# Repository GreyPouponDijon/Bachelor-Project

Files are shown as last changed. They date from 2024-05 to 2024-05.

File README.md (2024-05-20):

# Bachelor-Project
This project focused on developing a motion-controlled game for the Game Boy Pocket, integrating modern sensor technology with classic gaming hardware. The game, a first-person flying simulator, uses an accelerometer to detect motion, allowing players to control an aircraft by tilting the device. The accelerometer data is transmitted via SPI through a custom-made link cable, ensuring real-time movement.

Key Components
Game Development: Designed and programmed using GBDK-2020.
Sensor Integration: Implemented accelerometer data transmission via SPI.
Bluetooth Connectivity: Established connections using an nRF5340 module for multiplayer functionality, enabling competitive and cooperative gameplay.
Hardware Design: Created a prototype PCB to facilitate the integration process.
Challenges and Solutions
Hardware and Software Integration: Optimized performance within the constraints of the Game Boy Pocket’s limited memory and processing power.
Development Documentation: Thoroughly documented the development process from initial design to final implementation, detailing the methods used to overcome various challenges.
This project showcases the blend of retro gaming with modern technology, providing an innovative gaming experience on classic hardware.

The project report, PCB schematic, PCB files production files, BOM and code is available in this repo

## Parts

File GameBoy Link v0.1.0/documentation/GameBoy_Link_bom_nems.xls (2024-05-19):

Bill of material
Board: | <Parameter PCAName not found>
Version: | <Parameter PCARevision not found>
Number of boards: | 1
Designator | PartId | Total needed | Comment | Value | Footprint Doc | Description | Assembly | Layer | Quantity | Part number NEMS | Manufacturer | Manufacturer Part Number | Supplier 1 | Supplier Part Number 1 | Supplier 2 | Supplier Part Number 2
C1 | 100200441 | 1 |  | 0.7pF | 0201 | Capacitor, Ceramic, NP0, ±0.1pF, 25V |  | Top | 1 | 100200441 | Murata | GJM0335C1ER70BB01D | Digi-Key | 490-8076-1-ND | N.A. | N.A.
C2, C3, C5, C7, C16, C22 | 100200497 | 6 |  | 1.0µF | 0402 | Capacitor, Ceramic, 1.0µF 10V X7S 0402,±10% |  | Top | 6 | 100200497 | Murata | GRM155C71A105KE11 | Mouser | 81-GRM155C71A105KE1J | Digi-Key | 490-14457-1-ND
C4 | 100200060 | 1 |  | 2.2nF | 0201 | Capacitor, X7R, ±10%, 10V |  | Top | 1 | 100200060 | N.A. | N.A. | N.A. | N.A. | N.A. | N.A.
C6, C8, C9, C10, C11, C12, C13, C14, C15 | 100200403 | 9 |  | 100nF | 0201 | Capacitor, X7S, 16V |  | Top | 9 | 100200403 | Murata | GRM033C71C104KE14D | Digi-Key | 490-10387-1-ND | N.A. | N.A.
C17, C20 | 100200351 | 2 |  | 4.7µF | 0603 | Capacitor, X7S, ±10%, 10V |  | Top | 2 | 100200351 | N.A. | N.A. | Digi-Key | 445-14258-1-ND | N.A. | N.A.
C18 | 100200350 | 1 |  | 4.7µF | 0603 | Capacitor, X7R, ±10%, 6.3V |  | Top | 1 | 100200350 | Samsung Electro-Mechanics America | CL10B475KQ8NQNC | Digi-Key | 1276-2087-1-ND | N.A. | N.A.
C19 | 100200272 | 1 |  | 2.2µF | 0603 | Capacitor, X7R, ±10% |  | Top | 1 | 100200272 | N.A. | N.A. | N.A. | N.A. | N.A. | N.A.
C21 |  | 1 |  | N.C. | 0201 | Not mounted | Not mounted | Top | 1
C23 | 100200119 | 1 |  | 1.2pF | 0402 | Capacitor, NP0, ±0.1pF |  | Top | 1 | 100200119 | N.A. | N.A. | N.A. | N.A. | N.A. | N.A.
J1 | 100500400 | 1 |  | MM8130-2600 | COAXIAL-SWF | Coaxial Connector with Switch |  | Top | 1 | 100500400 | Murata | MM8130-2600 | Digi-Key | 490-4981-1-ND | Mouser | 81-MM8130-2600RA2
L1 | 100300209 | 1 |  | 2.2nH | 0201 | Inductor, 600mA, ±0.1ｎH, 120mOhm |  | Top | 1 | 100300209 | Murata | LQP03HQ2N2B02 | Digi-Key | 490-13899-1-ND | N.A. | N.A.
L2, L3, L4 | 100300078 | 3 |  | 10µH | 0603 | Inductor, 80mA, ±10% |  | Top | 3 | 100300078 | Taiyo Yuden | LBMF1608T100K | Digi-Key | 587-1714-1-ND | Farnell | 178-6105
LD1 | 101400017 | 1 |  | L0805G | 0805 | LED, SMD, 0805, GREEN |  | Top | 1 | 101400017 | Rohm Semiconductor | SML-210PTT86 | N.A. | N.A. | N.A. | N.A.
P1 | 100500318 | 1 |  | Pin List 1x6 | LIST_1x6 | Pin List 1x6, 2.54mm (100mil) |  | Top | 1 | 100500318 | N.A. | N.A. | N.A. | N.A. | N.A. | N.A.
P2 | 100500298 | 1 |  | Pin List 1x2 | LIST_1x2 | Pin List 1x2, 2.54mm (100mil) | Not mounted | Top | 1 | 100500298 | N.A. | N.A. | N.A. | N.A. | N.A. | N.A.
P3 | 100500261 | 1 |  | Pin Header 2x5, 1.27mm | HDR_2x5-SMD-1.27mm | Pin Header 2x5, 1.27mm (50mil), SMD, Keying Shroud |  | Top | 1 | 100500261 | WCON | 3132-10MS0BK00R5 | Cabcon | 3132-10MS0BK00R5 | N.A. | N.A.
R1 | 100100006 | 1 |  | 2R2 | 0201 | Resistor, ±1%, 0.05W |  | Top | 1 | 100100006 | N.A. | N.A. | N.A. | N.A. | N.A. | N.A.
R2 | 100100171 | 1 |  | 1k | 0402 | Resistor, ±1%, 0.063W |  | Top | 1 | 100100171 | N.A. | N.A. | Farnell | 173-8850 | N.A. | N.A.
SW1 | 101500001 | 1 |  | PB SW | Switch-PB-6.2x6.3mm-SMD | Tactile Switch, SPNO, SMD, 160gf, 6.2x6.3x2.5mm | DNM | Top | 1 | 101500001, 101500133 | Dailywell | TS604VM1-025BR-R | Cabcon | TS604VM1-025BR-R | Mouser | 688-SKHUALE010
U1 | 102000153 | 1 |  | nRF5340-QKAA | AQFN-98 | Multi-protocol Bluetooth Low Energy, IEEE 802.15.4, ANT and 2.4GHz proprietary system-on-chip |  | Top | 1 | 102000153 | Nordic Semiconductor | nRF5340-QKAA | Nordic Semiconductor | nRF5340-QKAA | N.A. | N.A.
U2 | 101900620 | 1 |  | BMI270 | LGA-14 | 6-axis, smart, low-power, inertial measurement unit |  | Top | 1 | 101900620 | Bosch | BMI270 | Digi-Key | 828-1091-1-ND | Mouser | 262-BMI270
X1 | 101600041 | 1 |  | 32MHz | XTAL_2016 | XTAL SMD 2016, 32MHz, Cl=8pF, Tol: ±10ppm, Stab: ±15ppm |  | Top | 1 | 101600041 | Golledge | MP06003 | Link Nordic | N.A. | N.A. | N.A.
PCB |  | 1 |  | <Parameter PCBNumber not found> | <Parameter PCBRevision not found> |  |  |  | 1
All components must be RoHS compliant

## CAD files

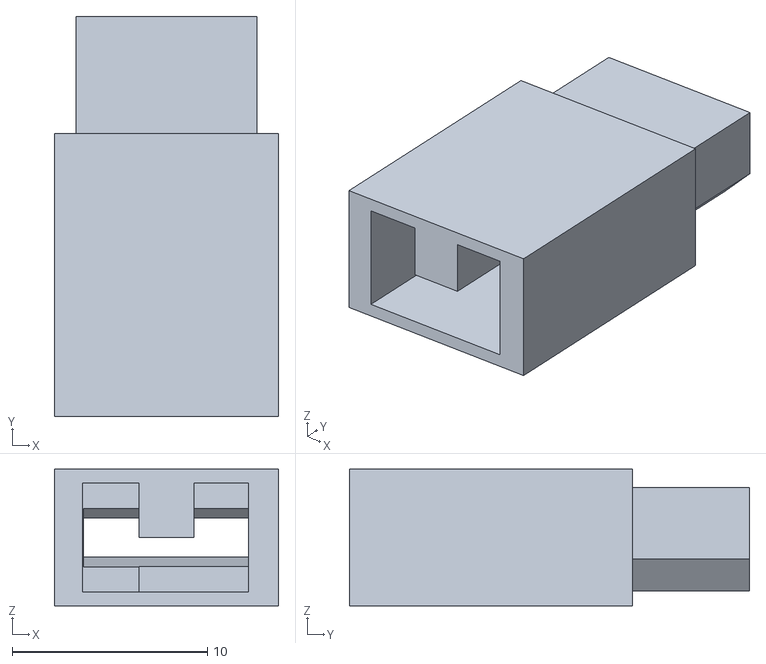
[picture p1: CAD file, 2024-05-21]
Link Cable GBP.stl
11.5 x 20.5 x 7.00

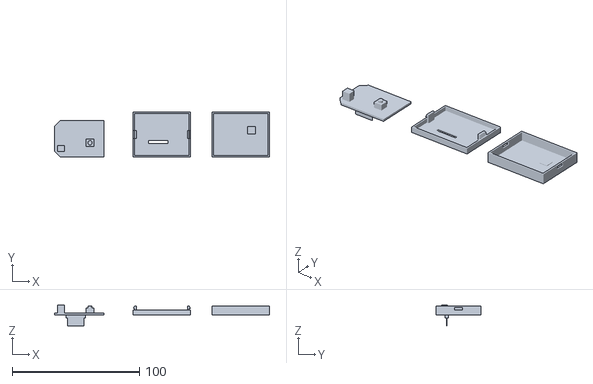
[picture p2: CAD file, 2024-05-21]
Gamelink.stl
168.7 x 35.0 x 16.1

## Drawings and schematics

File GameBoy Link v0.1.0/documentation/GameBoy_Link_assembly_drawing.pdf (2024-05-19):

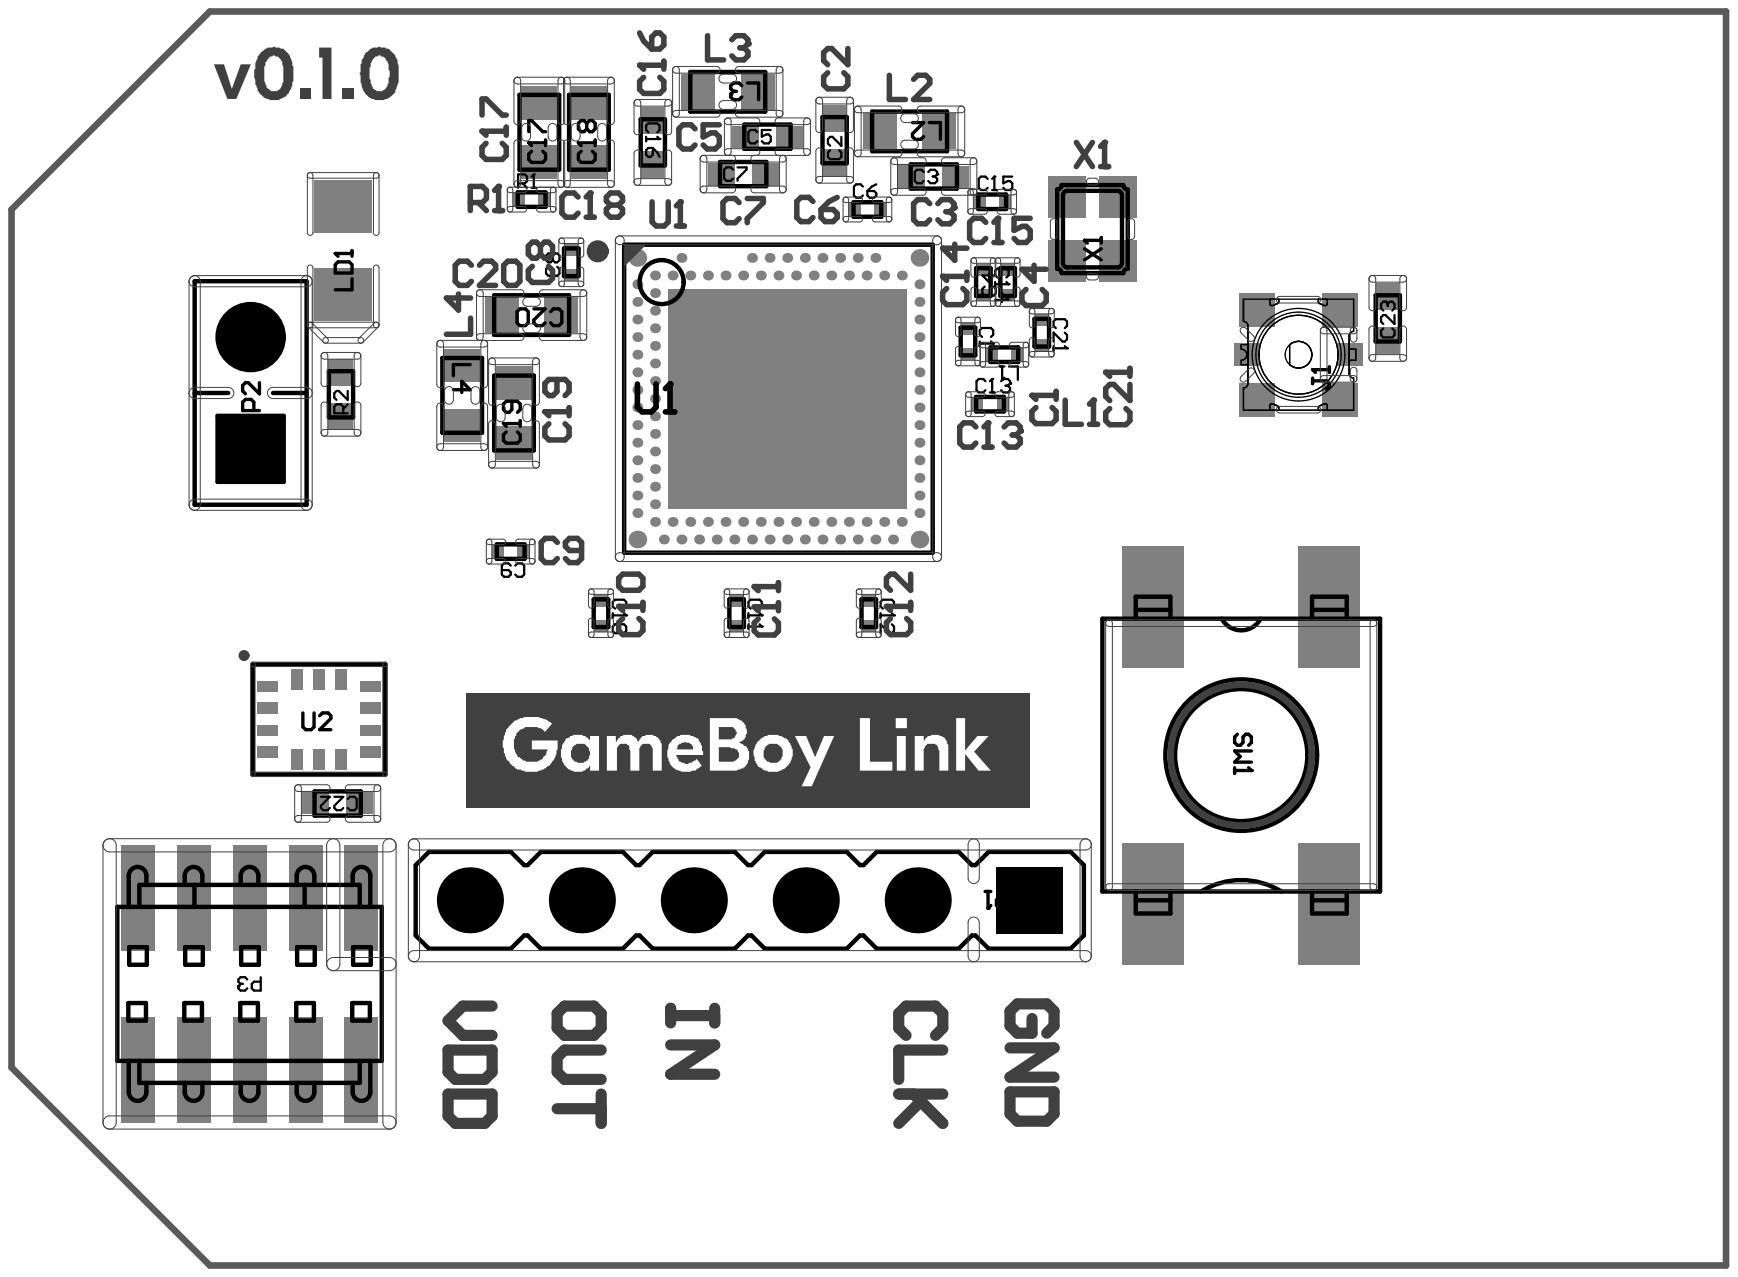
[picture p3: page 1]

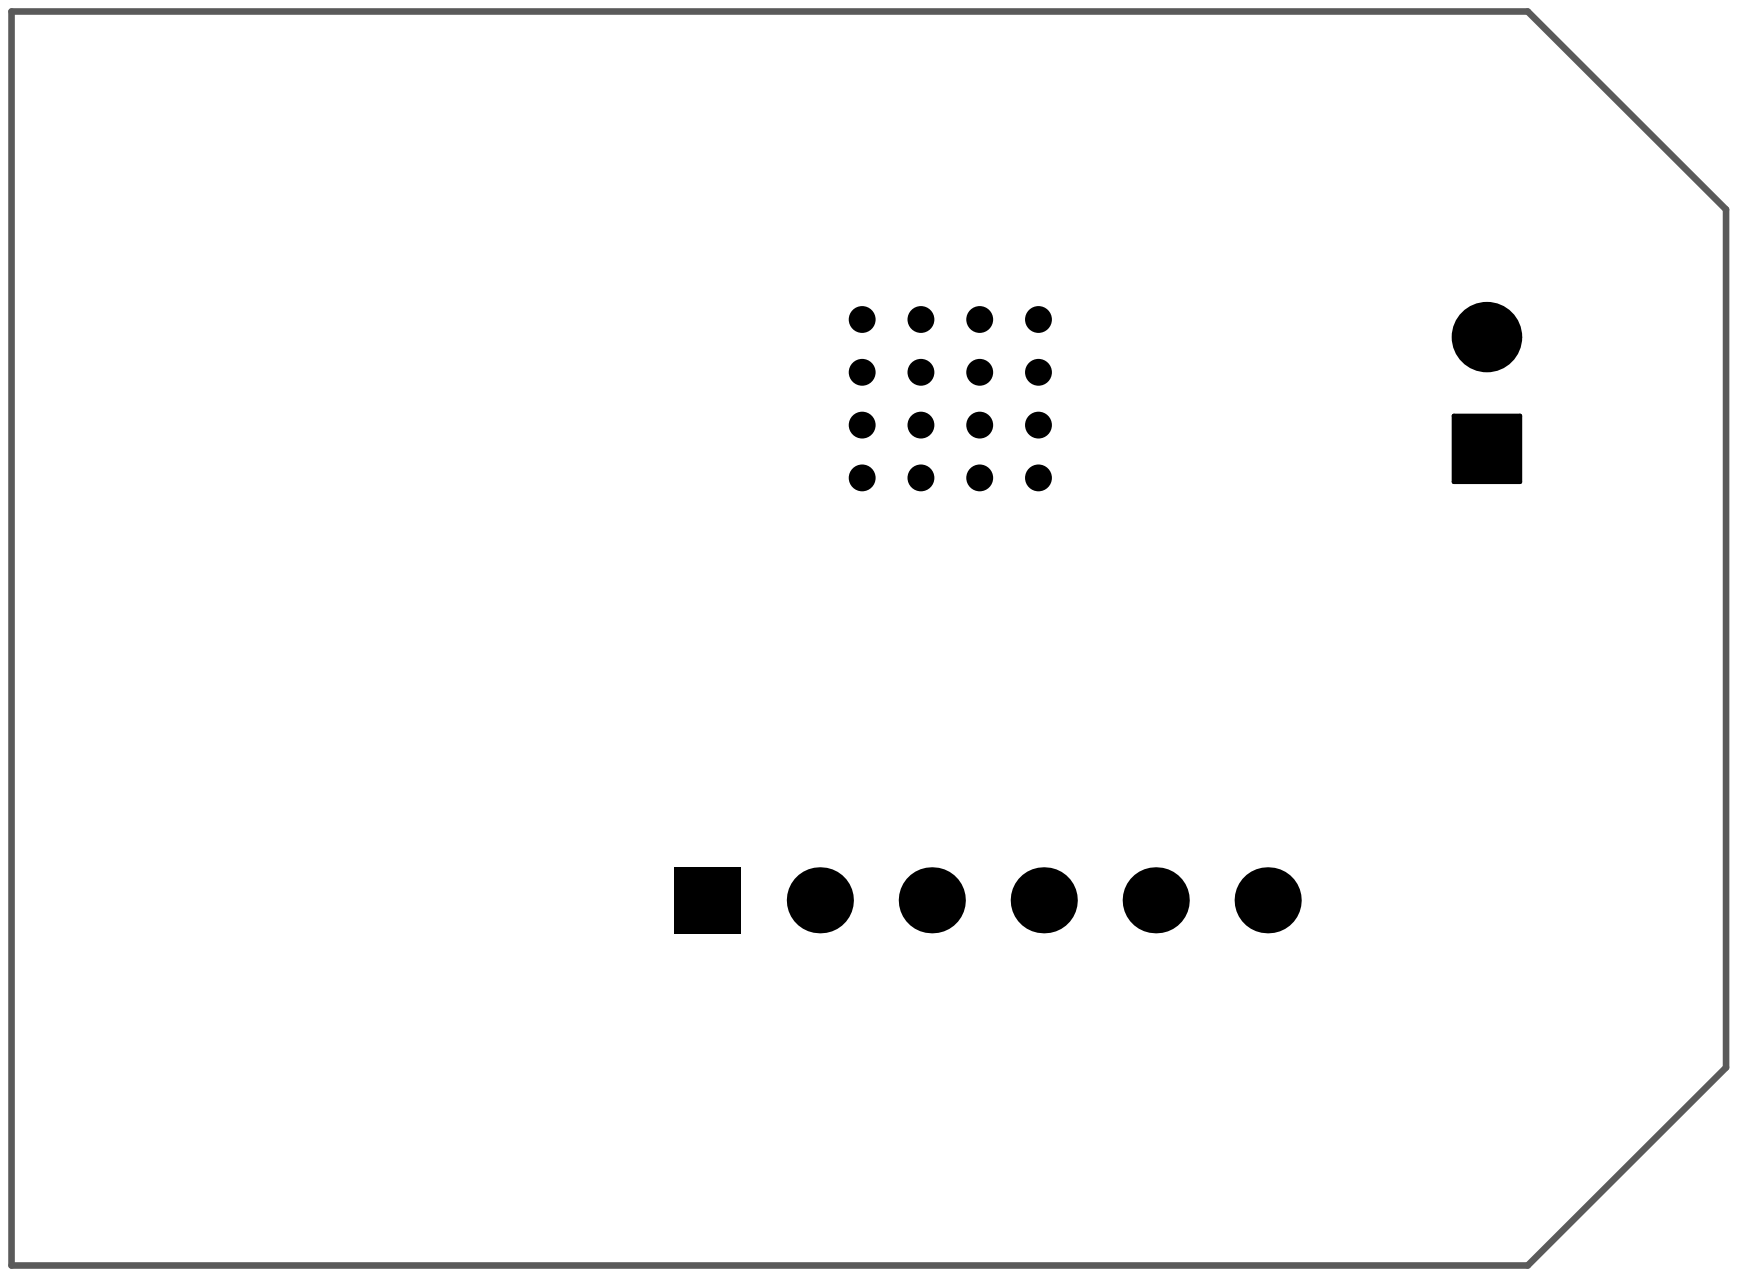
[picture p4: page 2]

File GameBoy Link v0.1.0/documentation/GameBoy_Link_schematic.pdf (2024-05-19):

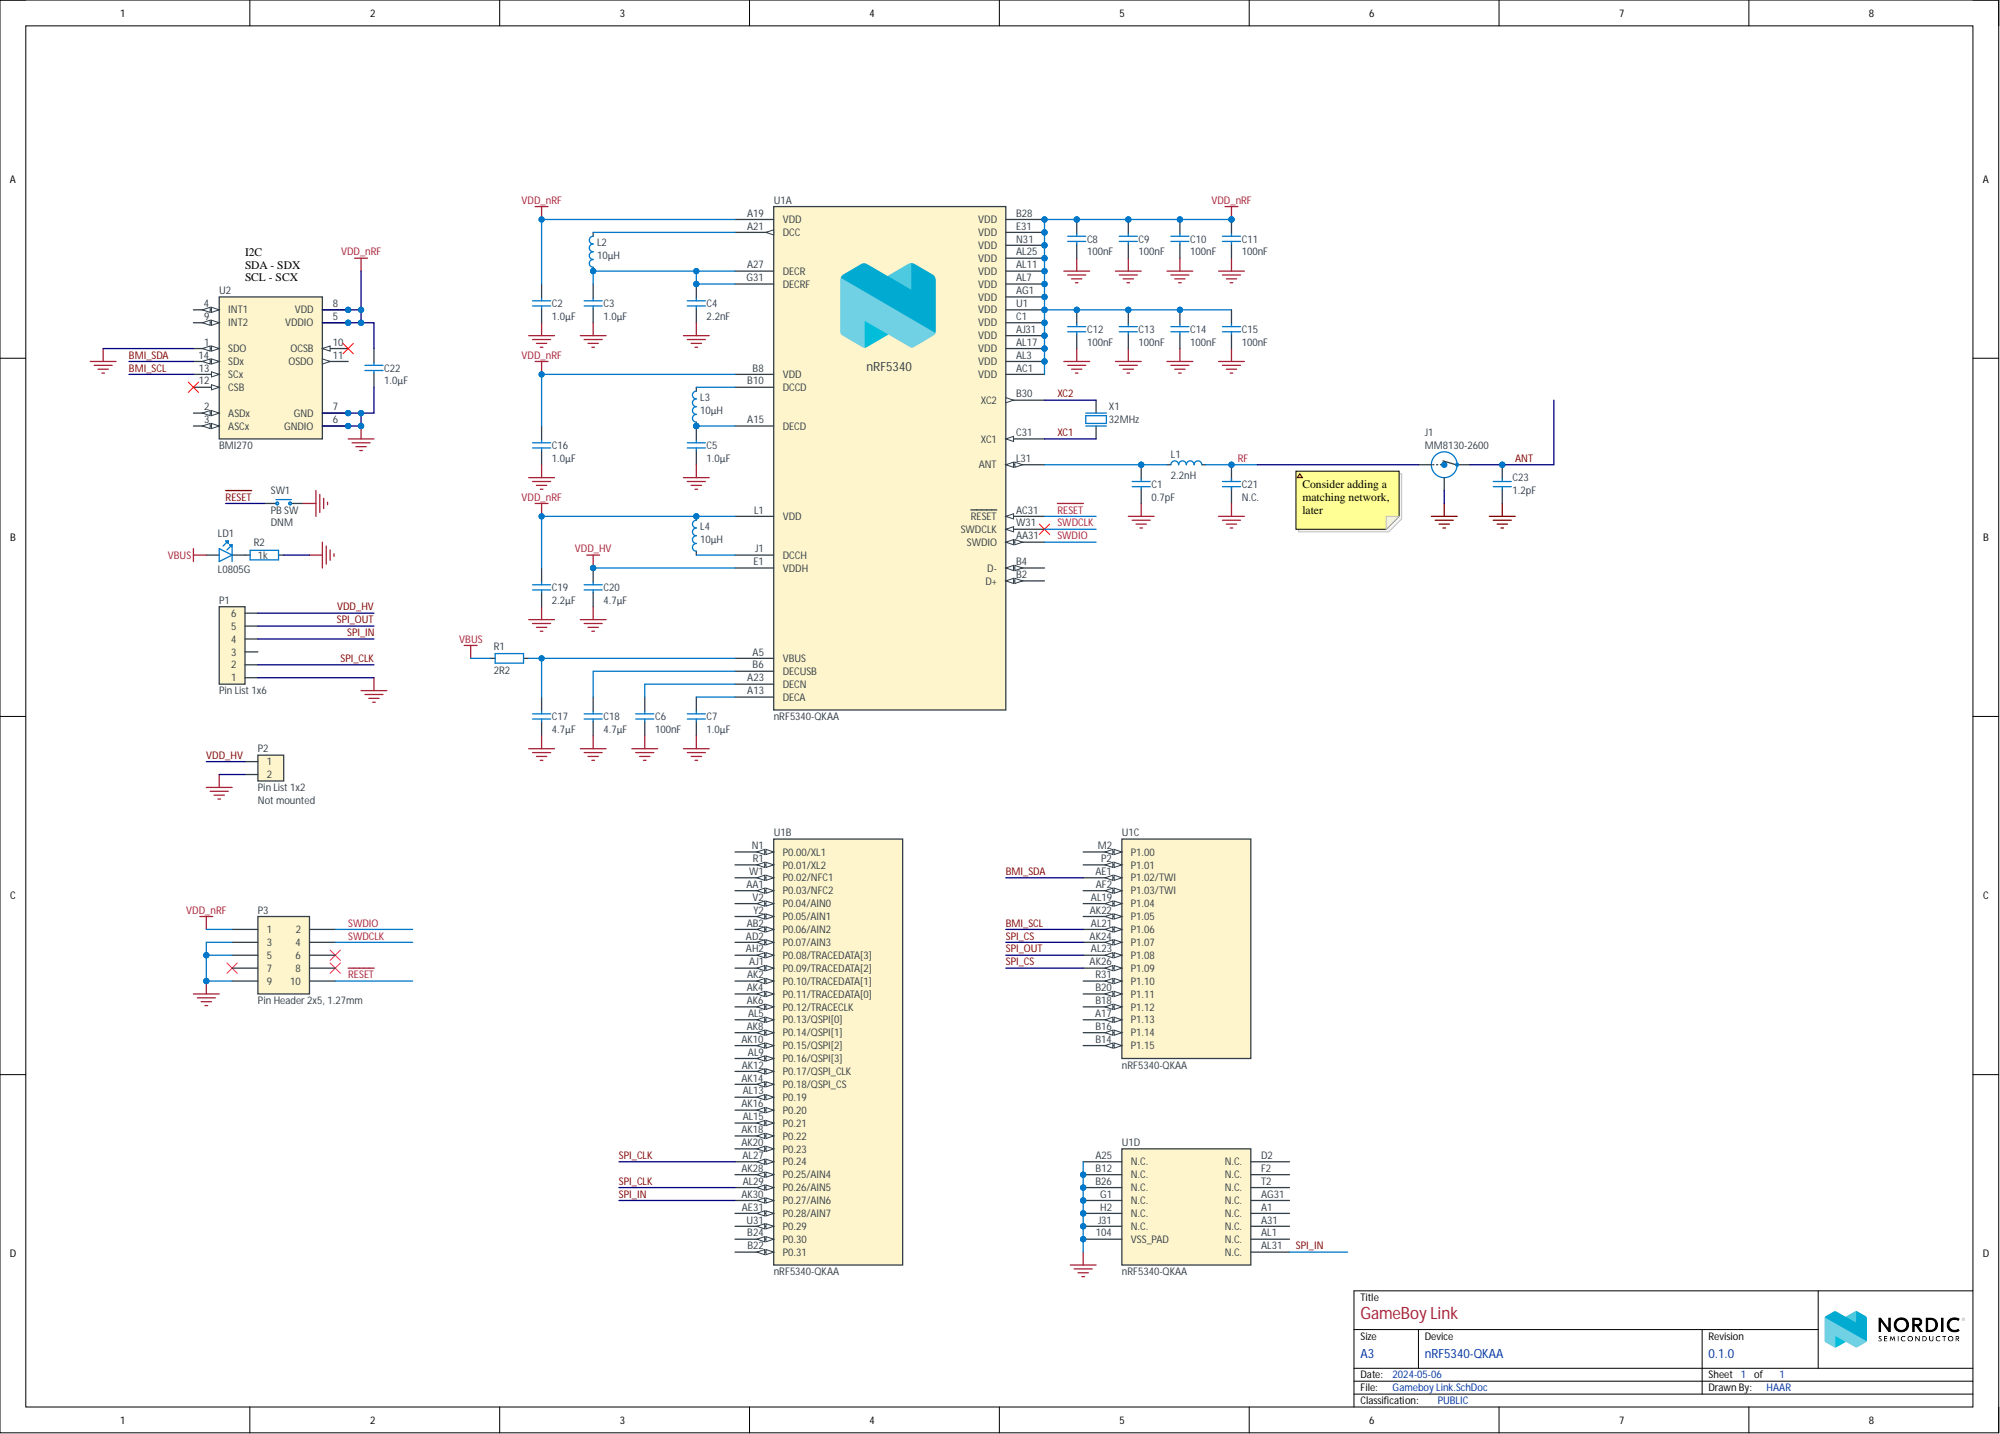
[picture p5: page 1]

DCC A21

DECRF G31

VDD B8
DCCD B10

VBUS A5

DECA A13 DECN A23

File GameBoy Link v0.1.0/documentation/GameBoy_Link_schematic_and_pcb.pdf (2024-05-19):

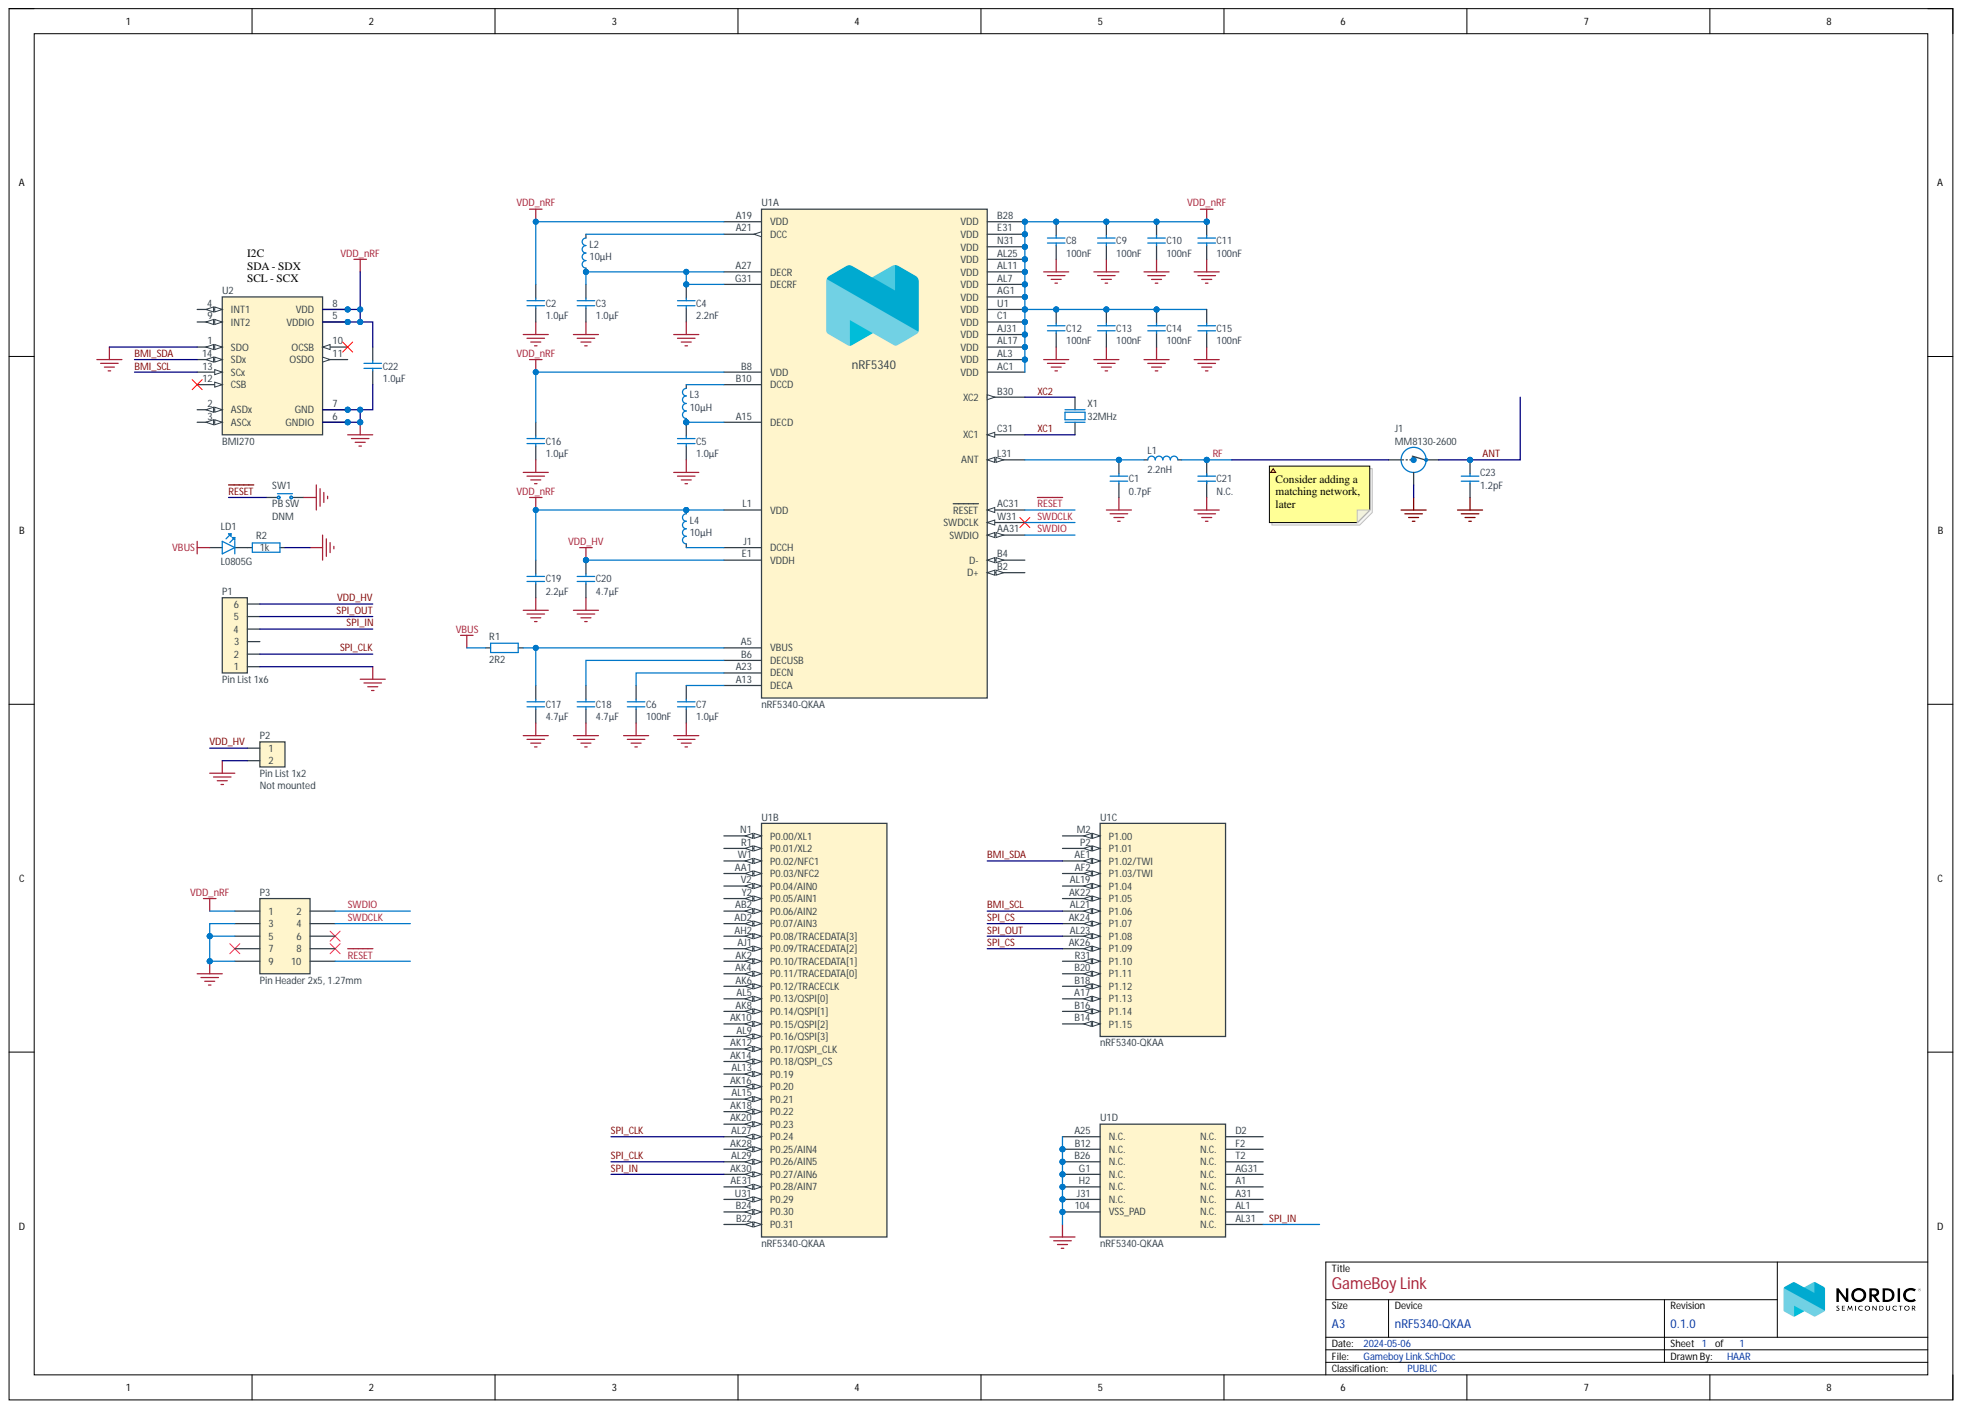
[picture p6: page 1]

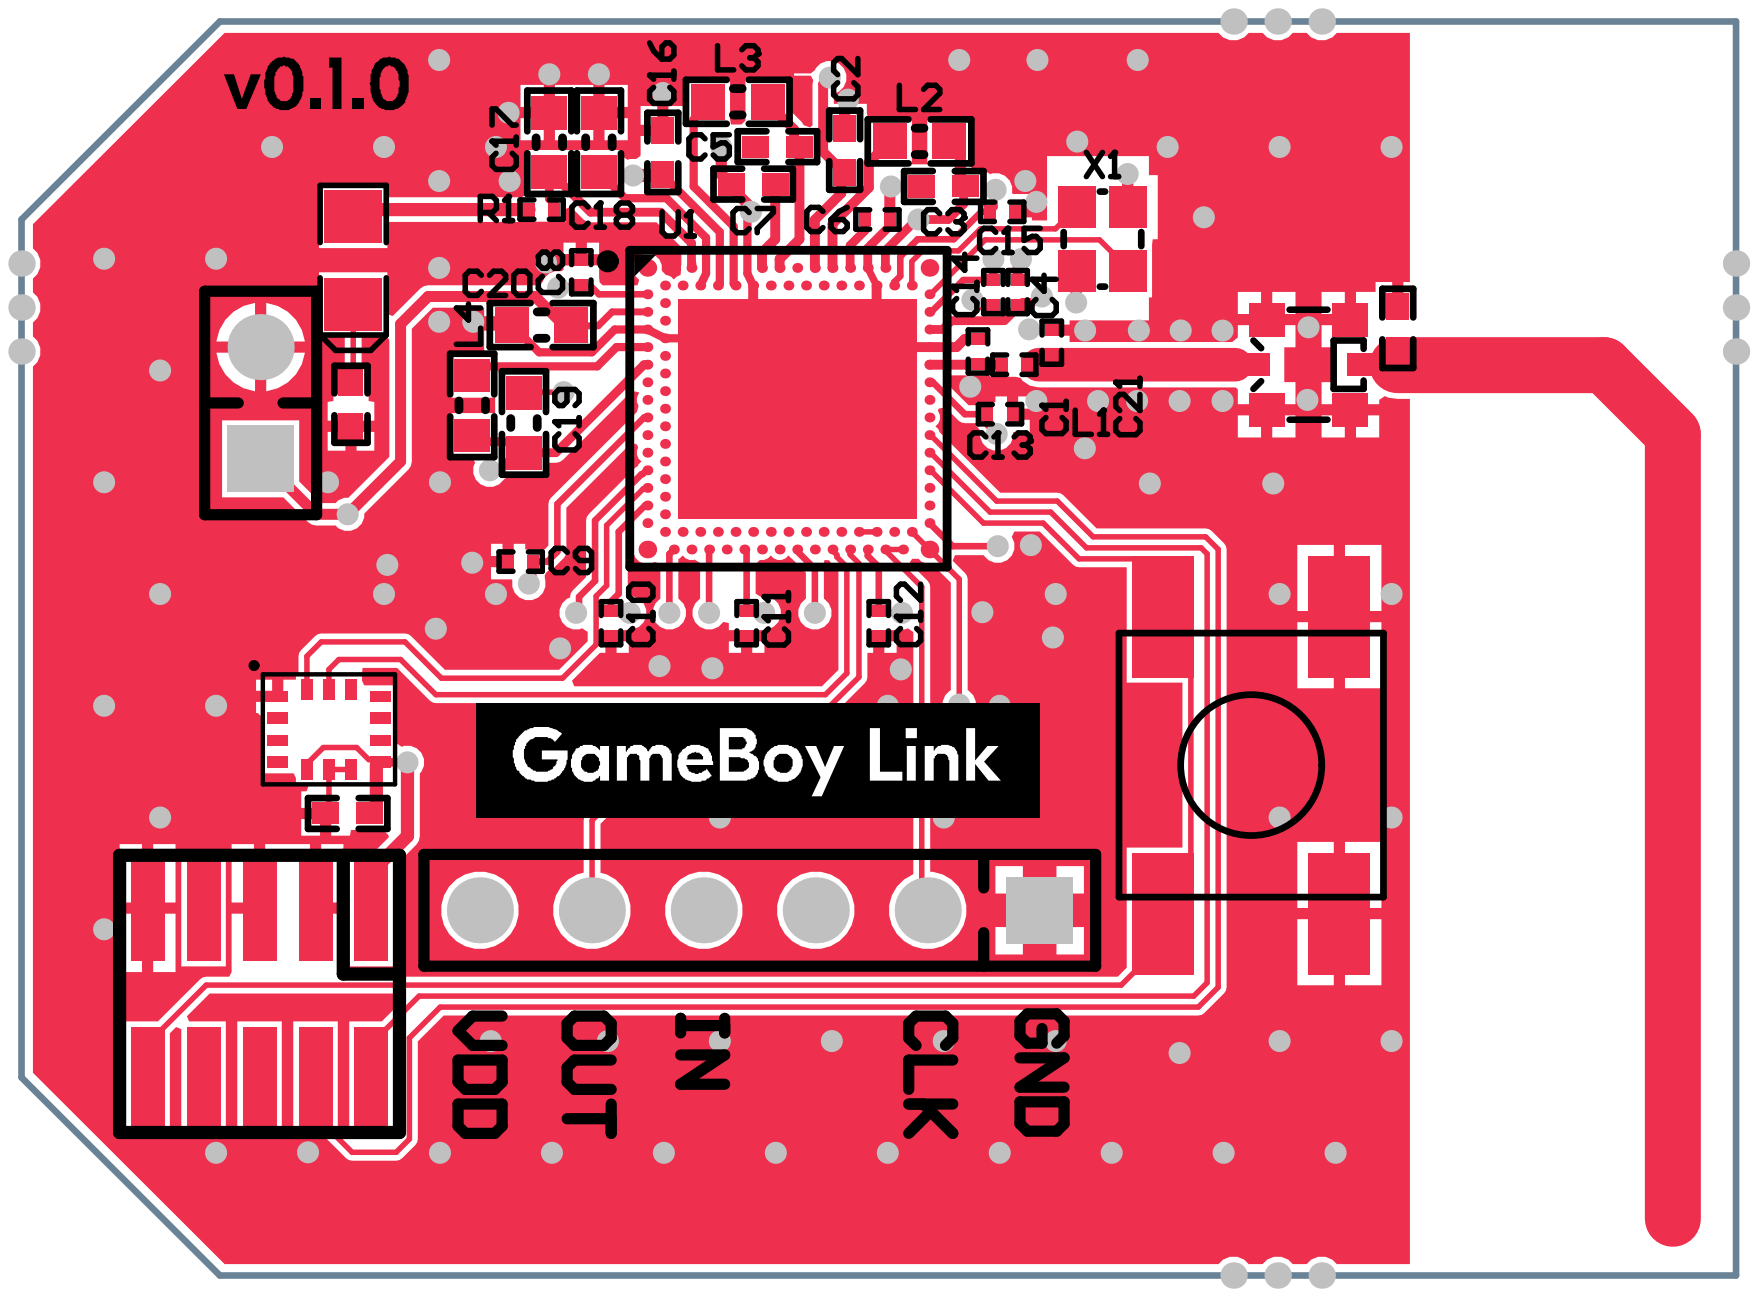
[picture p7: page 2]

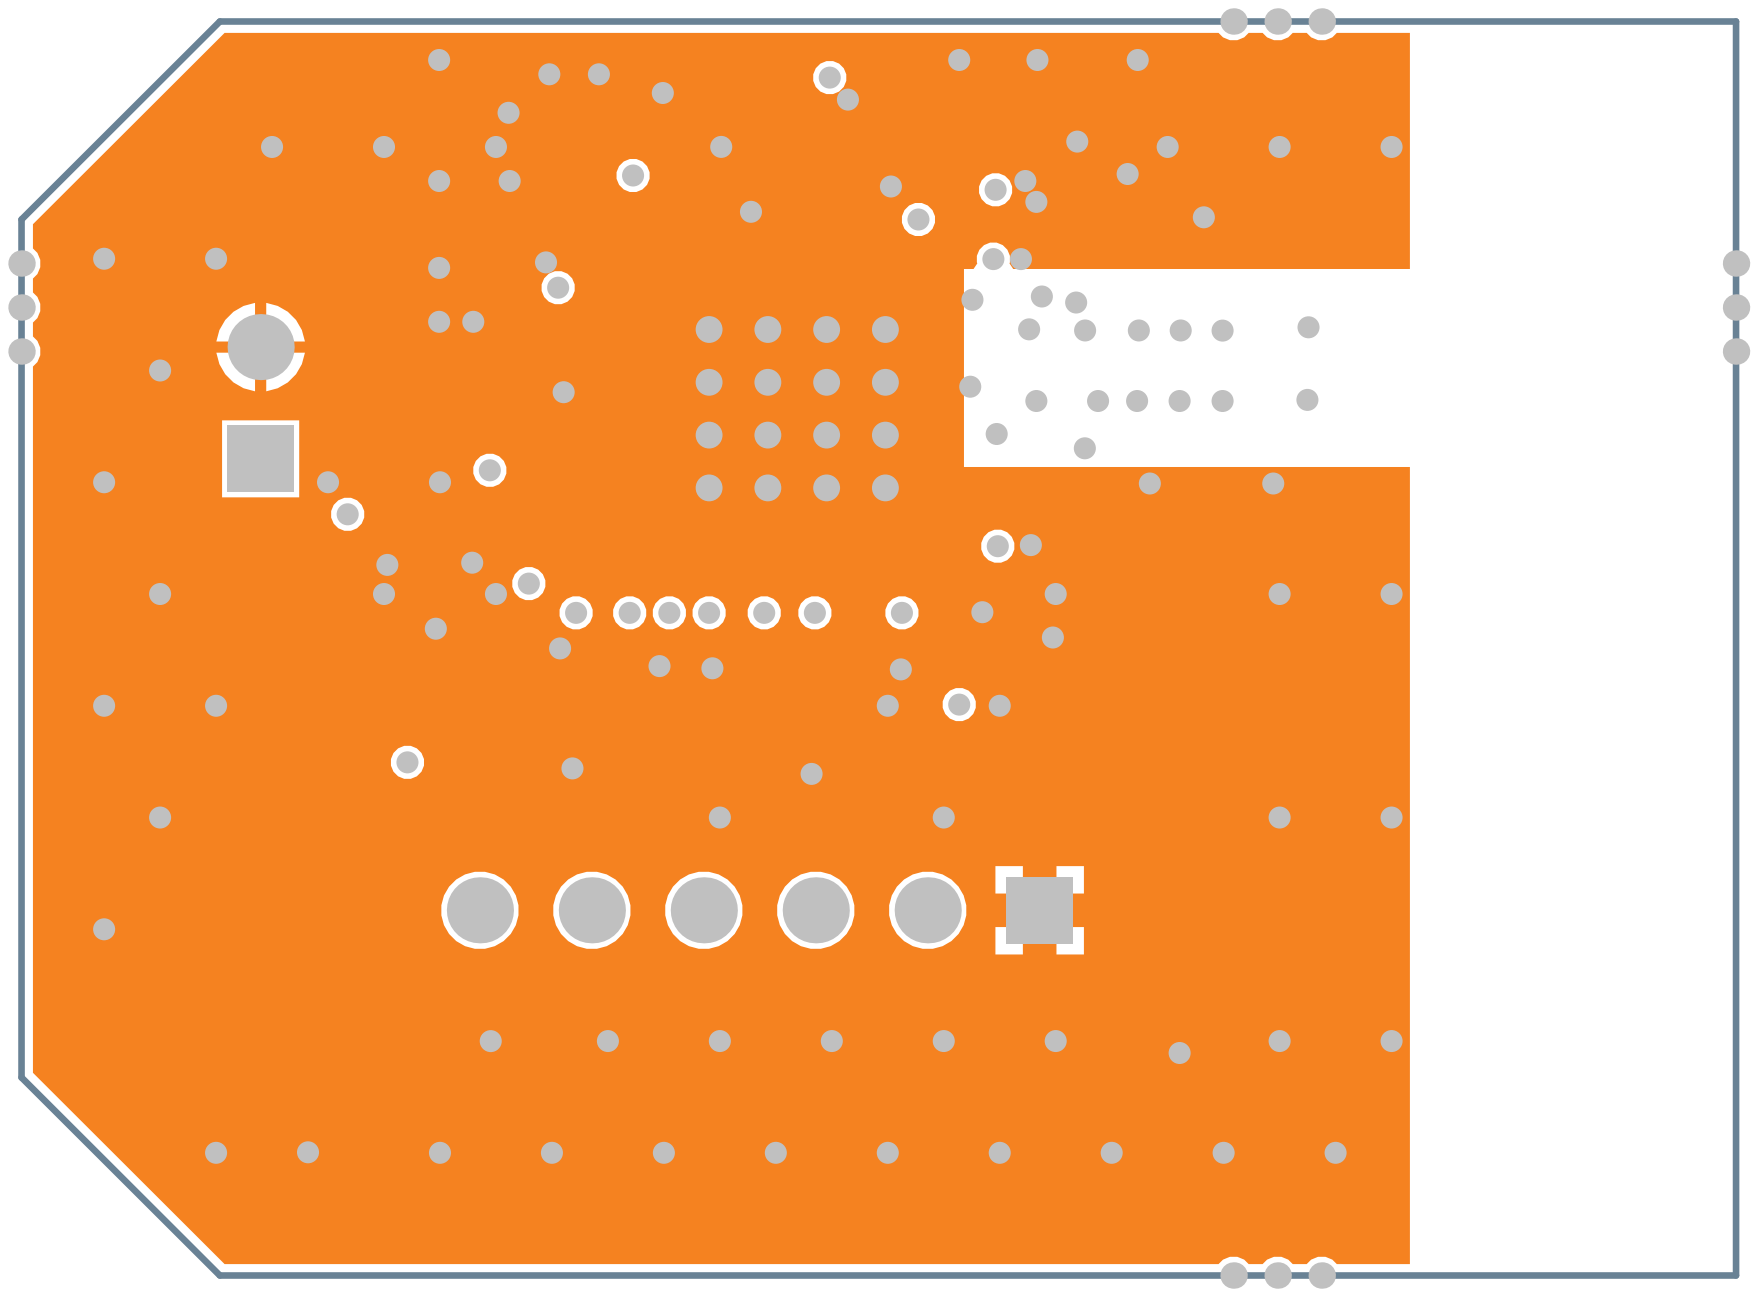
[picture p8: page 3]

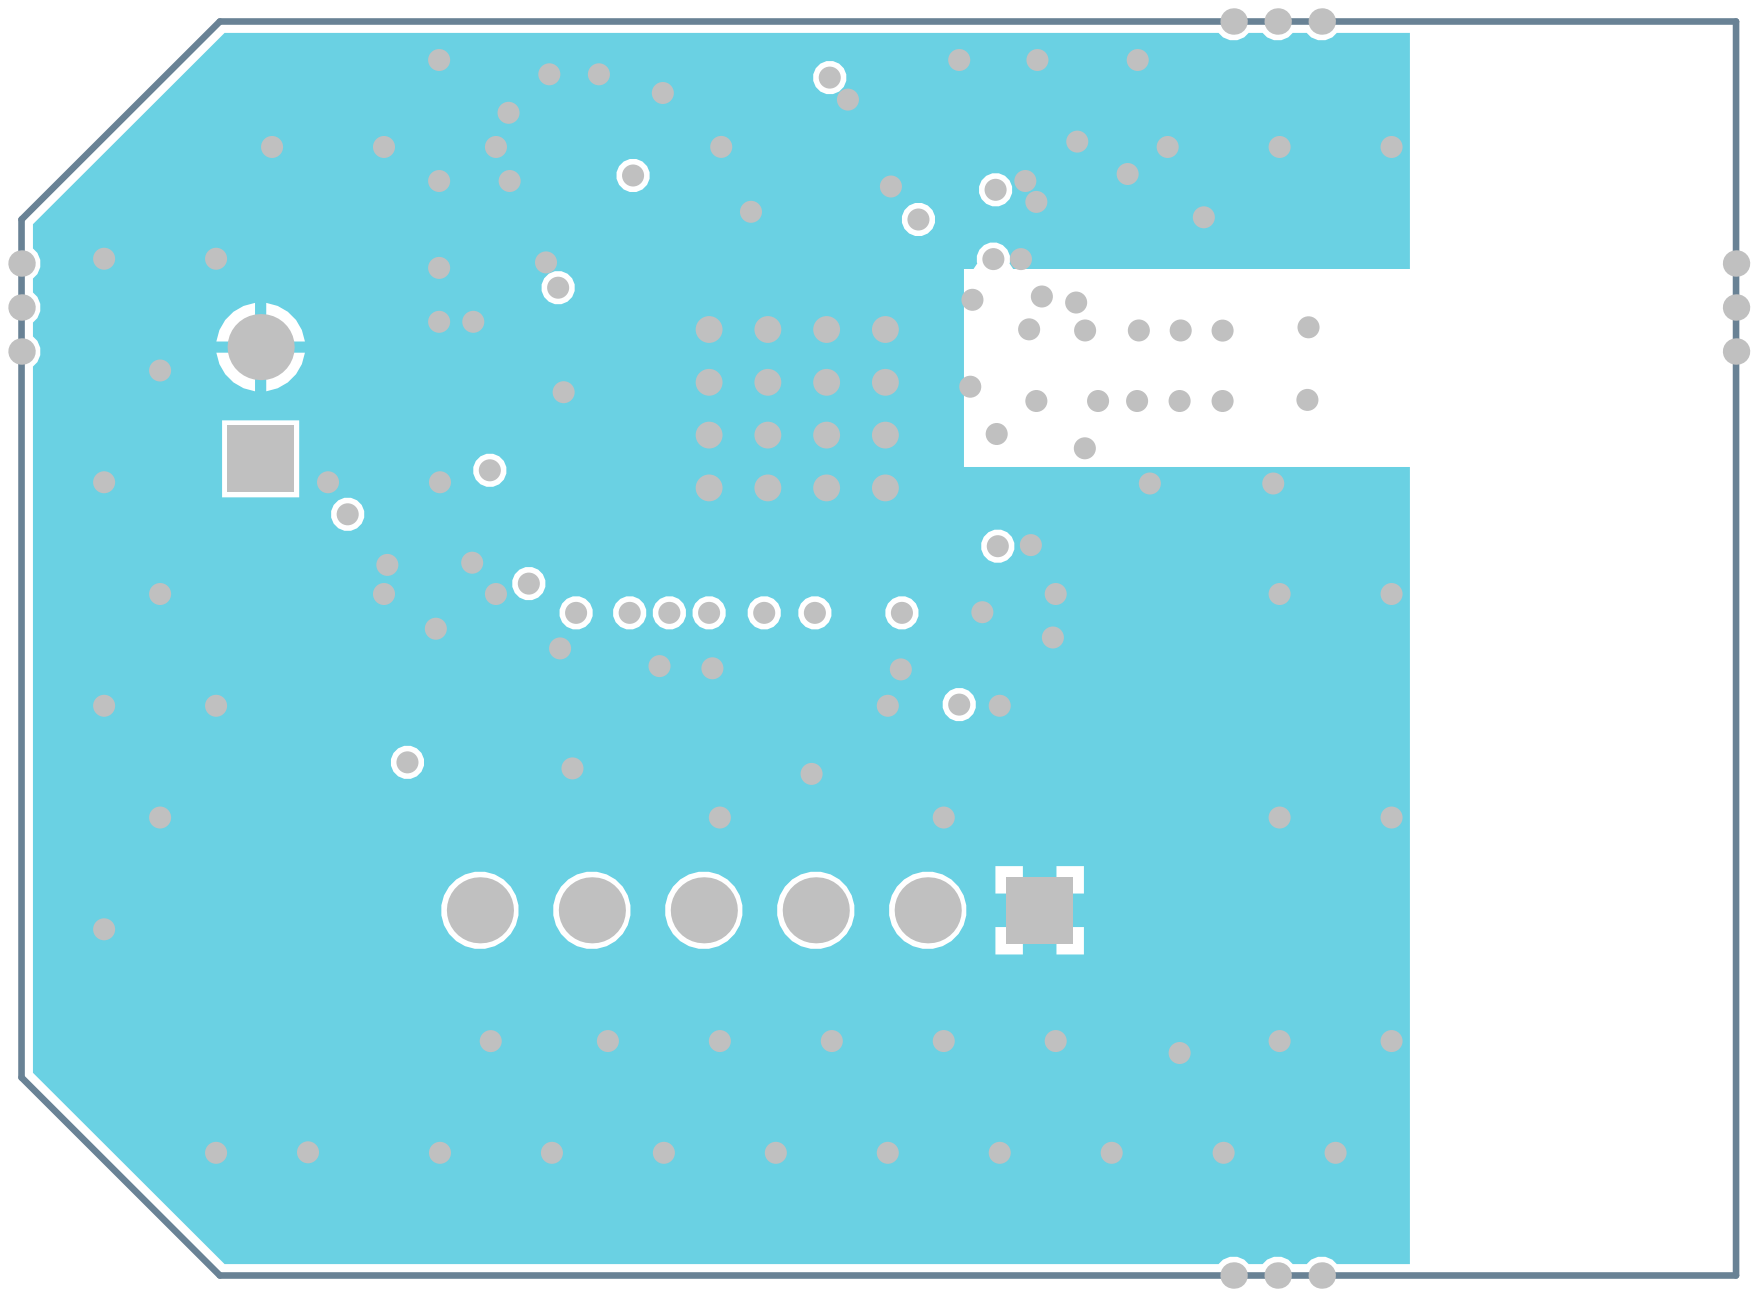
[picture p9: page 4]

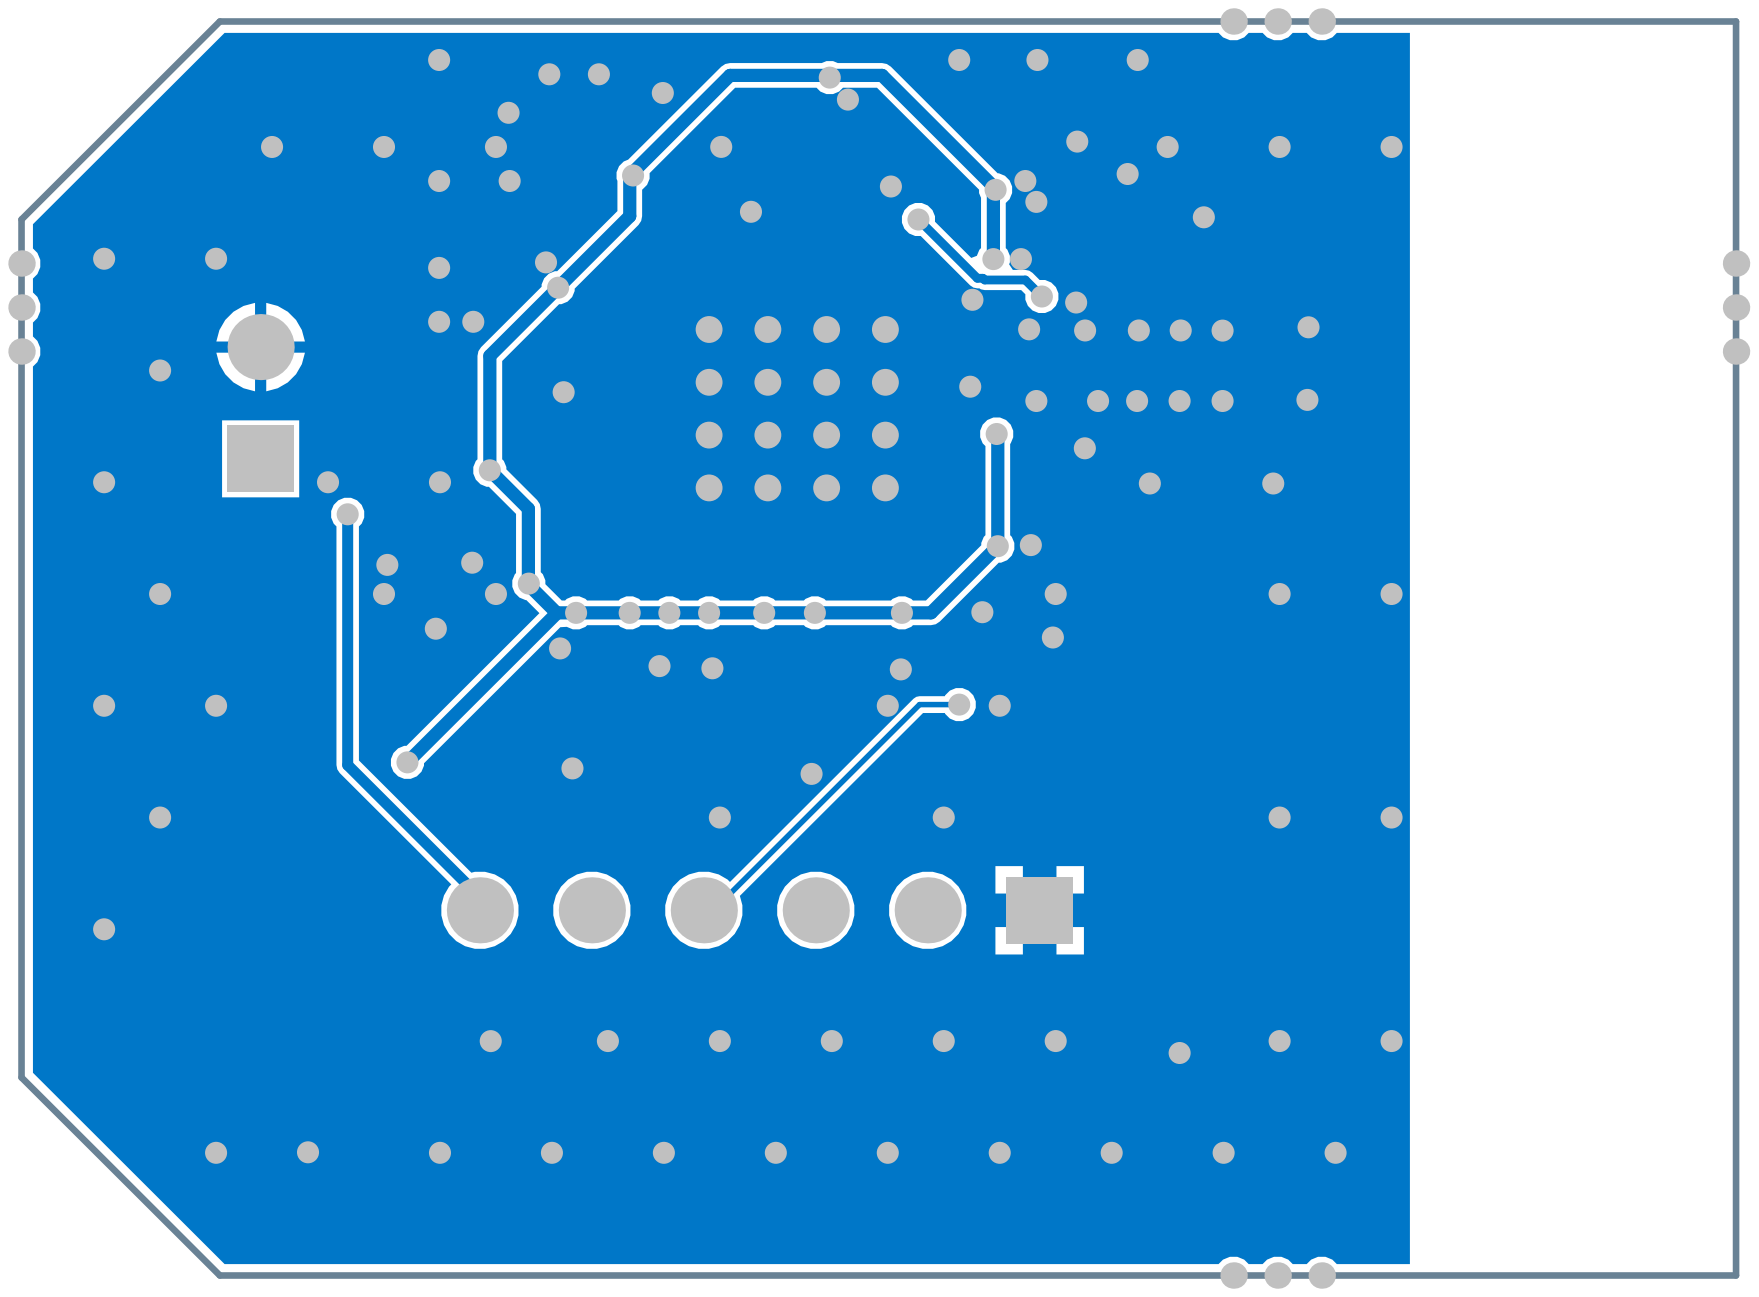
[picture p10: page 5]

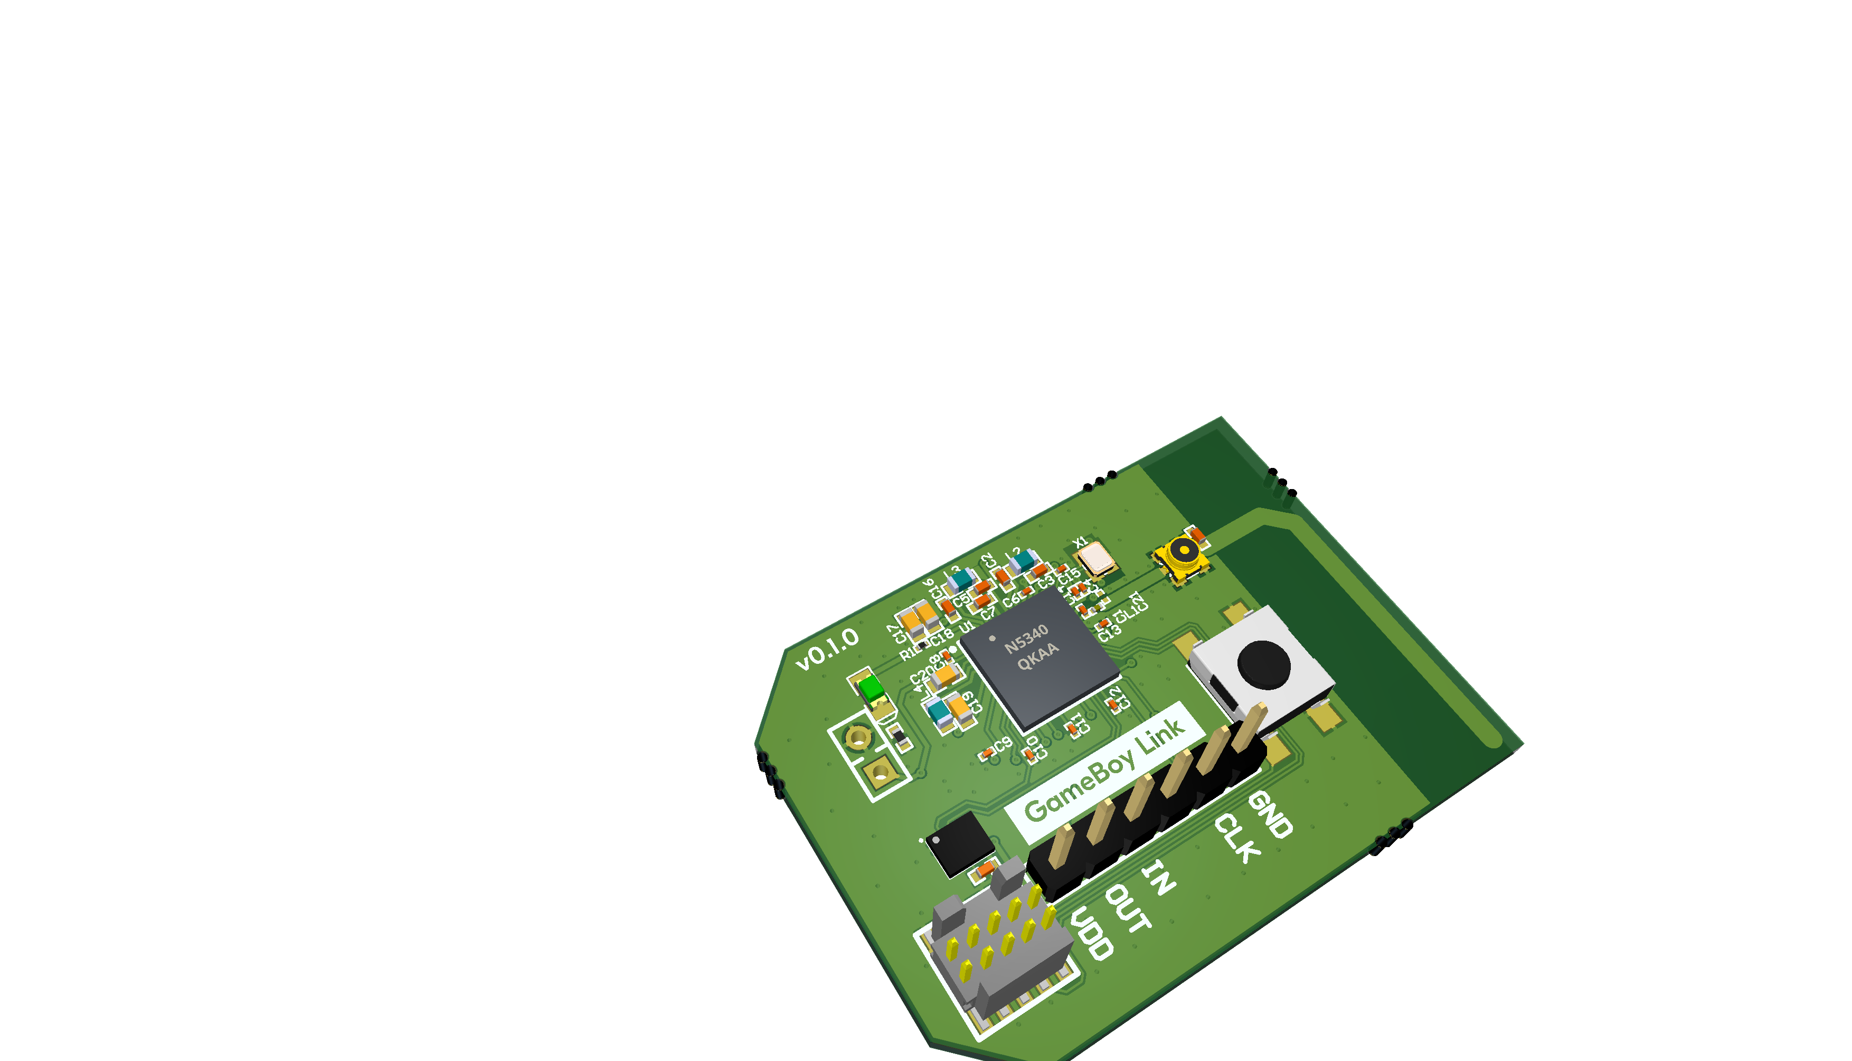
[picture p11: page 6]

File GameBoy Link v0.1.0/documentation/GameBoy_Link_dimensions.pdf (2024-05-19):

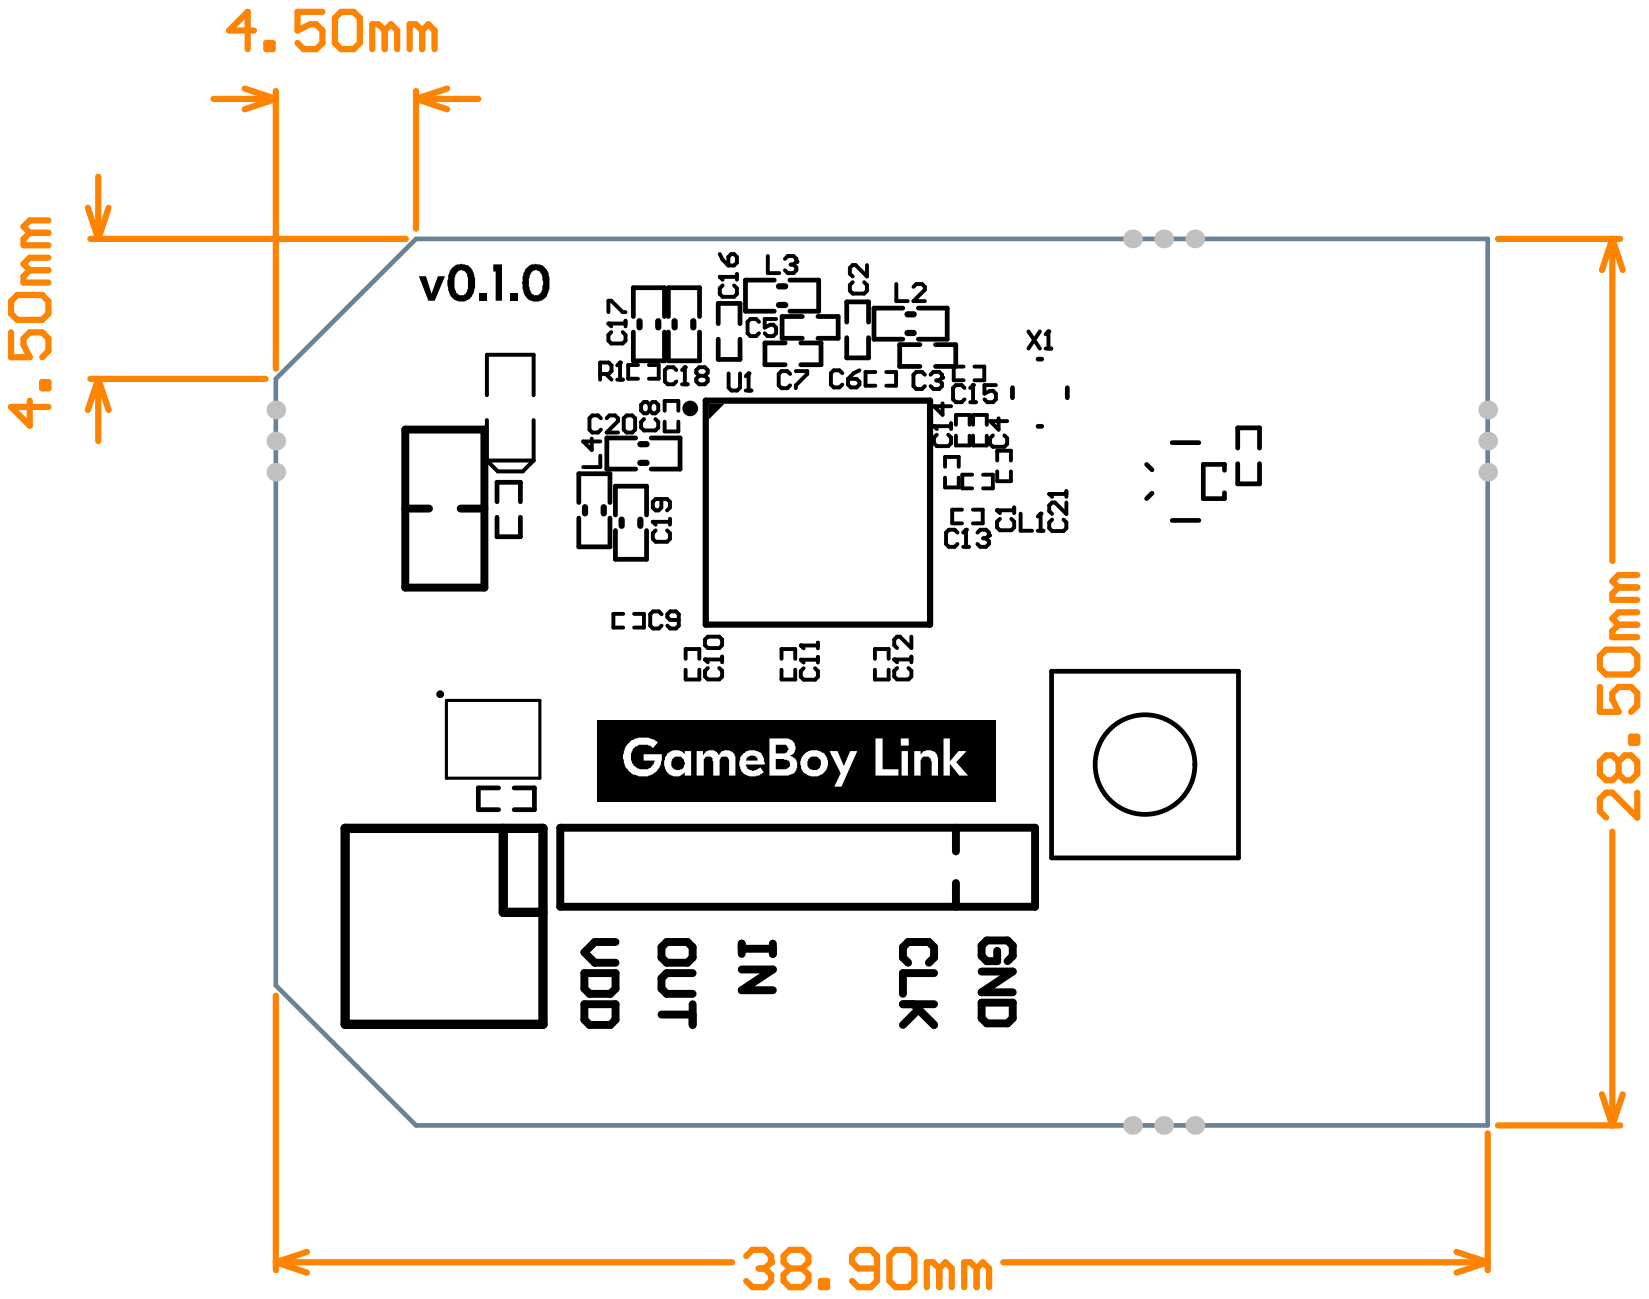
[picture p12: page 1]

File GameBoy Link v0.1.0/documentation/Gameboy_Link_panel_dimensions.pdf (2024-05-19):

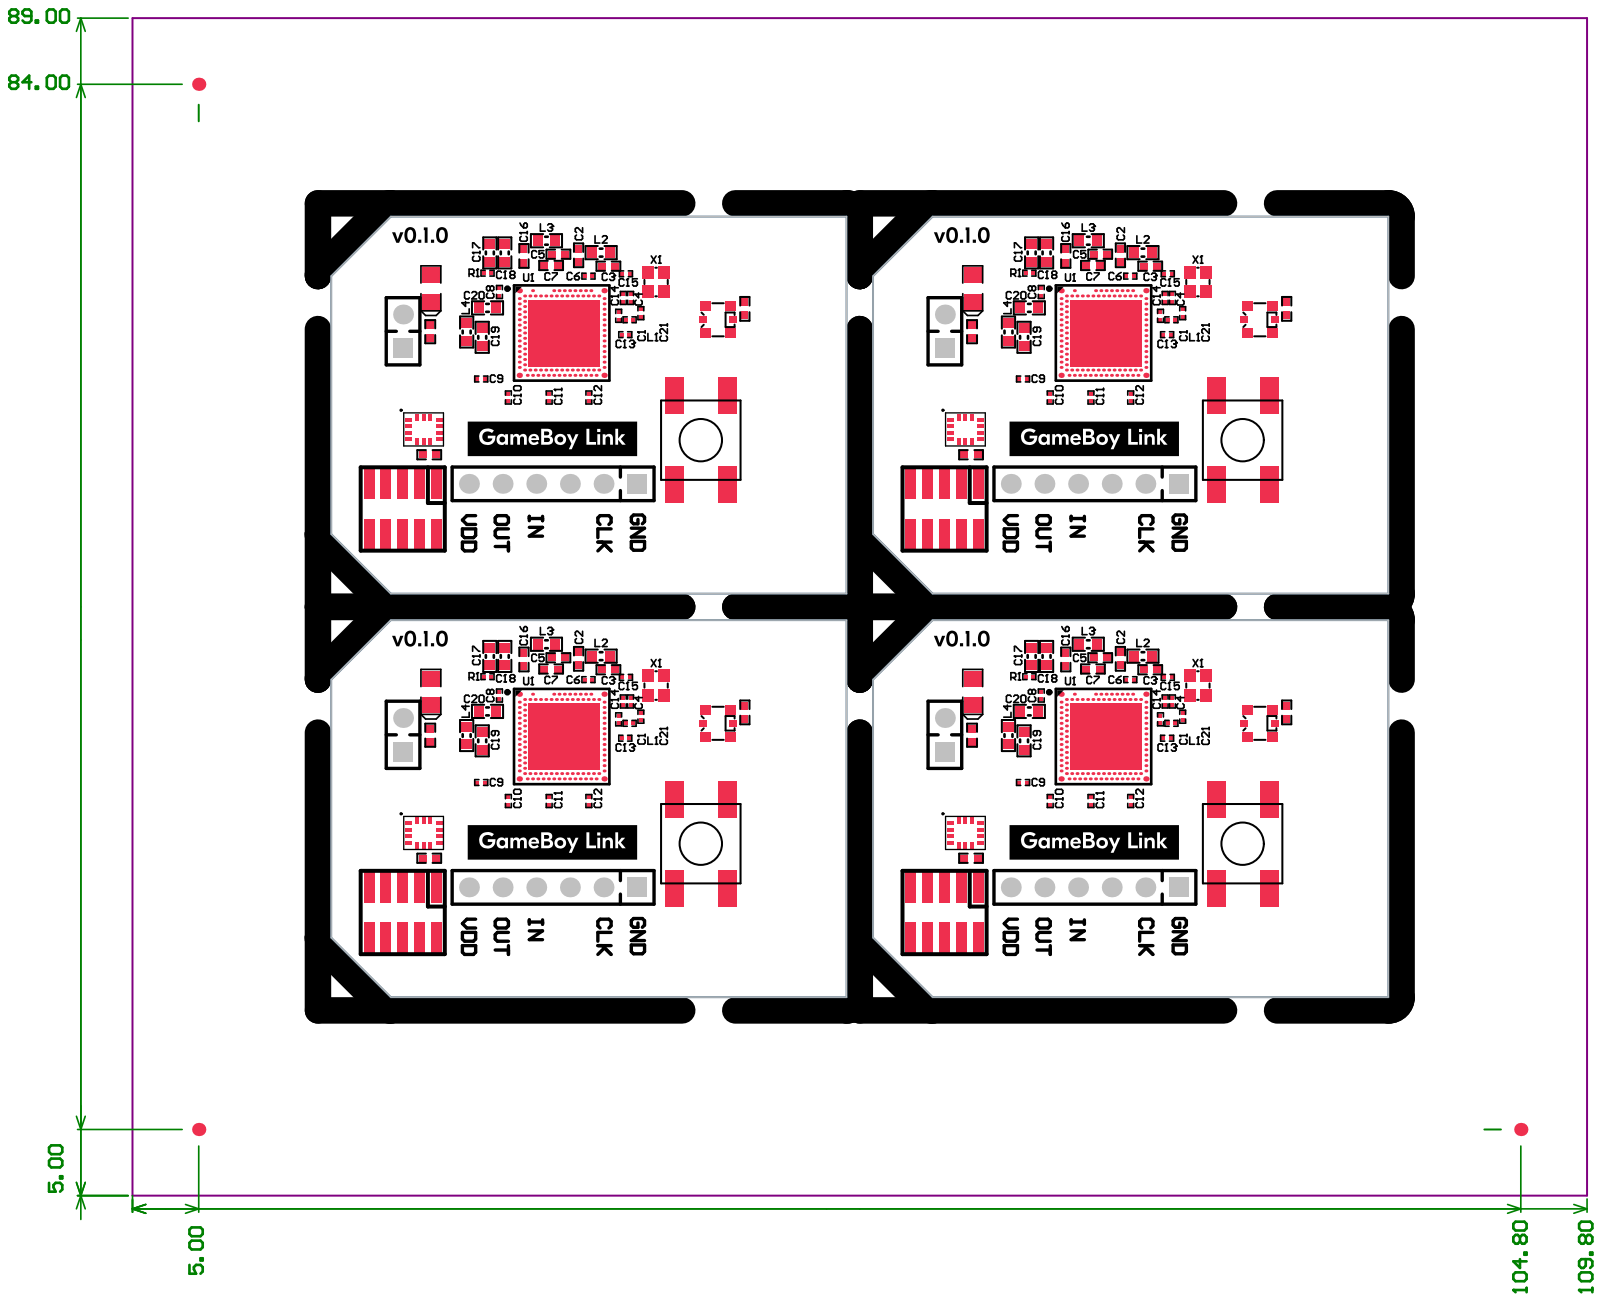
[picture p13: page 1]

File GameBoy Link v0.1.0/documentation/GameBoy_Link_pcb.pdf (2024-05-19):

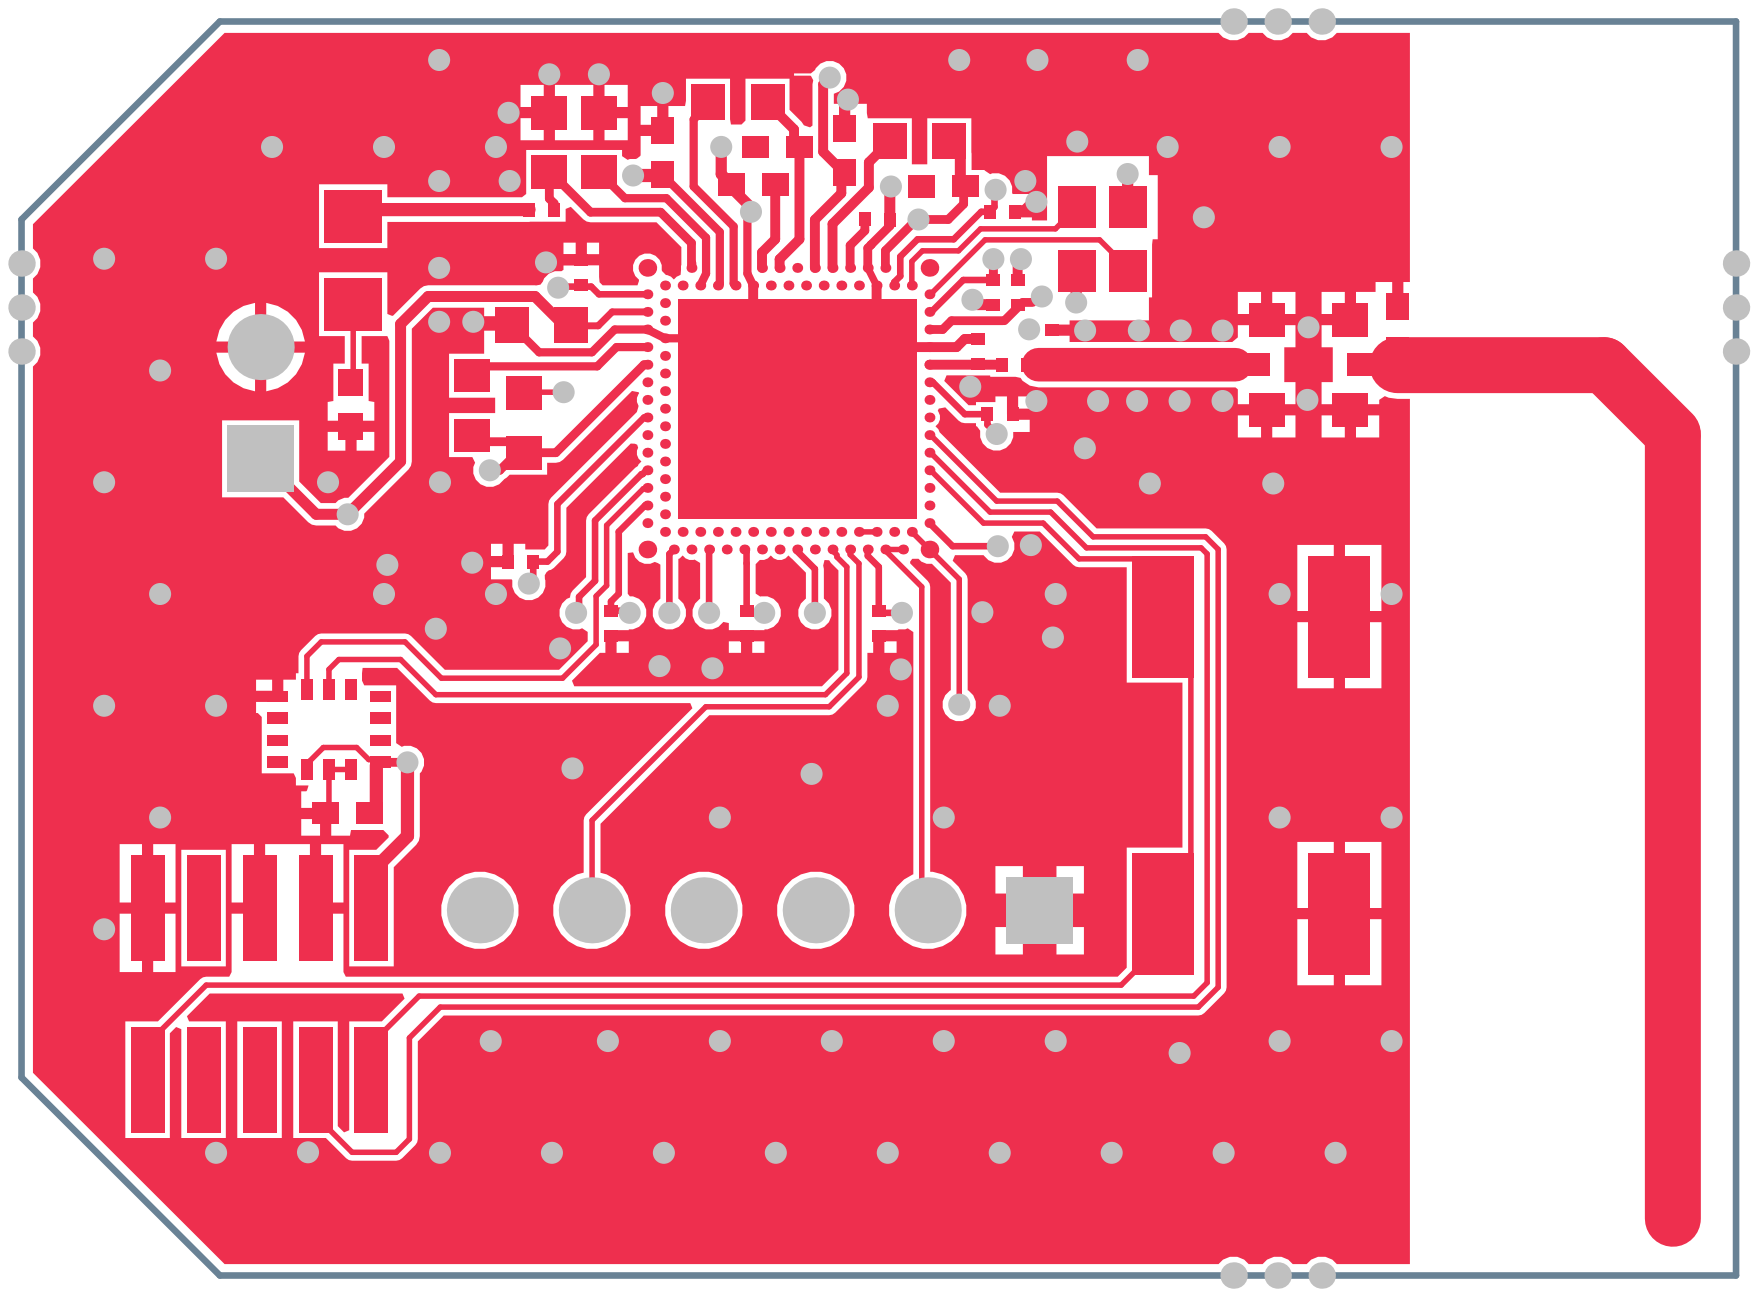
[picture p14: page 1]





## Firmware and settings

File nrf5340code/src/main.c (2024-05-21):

/*
 * Copyright (c) 2021 Bosch Sensortec GmbH
 *
 * SPDX-License-Identifier: Apache-2.0
 */

/*
 * Copyright (c) 2022 - 2023, Nordic Semiconductor ASA
 * All rights reserved.
 *
 * SPDX-License-Identifier: BSD-3-Clause
 *
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
 * 2. Redistributions in binary form must reproduce the above copyright
 *    notice, this list of conditions and the following disclaimer in the
 *    documentation and/or other materials provided with the distribution.
 *
 * 3. Neither the name of the copyright holder nor the names of its
 *    contributors may be used to endorse or promote products derived from this
 *    software without specific prior written permission.
 *
 * THIS SOFTWARE IS PROVIDED BY THE COPYRIGHT HOLDERS AND CONTRIBUTORS "AS IS"
 * AND ANY EXPRESS OR IMPLIED WARRANTIES, INCLUDING, BUT NOT LIMITED TO, THE
 * IMPLIED WARRANTIES OF MERCHANTABILITY AND FITNESS FOR A PARTICULAR PURPOSE
 * ARE DISCLAIMED. IN NO EVENT SHALL THE COPYRIGHT HOLDER OR CONTRIBUTORS BE
 * LIABLE FOR ANY DIRECT, INDIRECT, INCIDENTAL, SPECIAL, EXEMPLARY, OR
 * CONSEQUENTIAL DAMAGES (INCLUDING, BUT NOT LIMITED TO, PROCUREMENT OF
 * SUBSTITUTE GOODS OR SERVICES; LOSS OF USE, DATA, OR PROFITS; OR BUSINESS
 * INTERRUPTION) HOWEVER CAUSED AND ON ANY THEORY OF LIABILITY, WHETHER IN
 * CONTRACT, STRICT LIABILITY, OR TORT (INCLUDING NEGLIGENCE OR OTHERWISE)
 * ARISING IN ANY WAY OUT OF THE USE OF THIS SOFTWARE, EVEN IF ADVISED OF THE
 * POSSIBILITY OF SUCH DAMAGE.
 */

/*
*	This is main file for the nRF5340 part of this project and includes the initialization of Bluetooth and the nrfx timer.
*	The threads running in this main are the main thread responsible for choosing Bluetooth role and sending messages
*	The Obtain value thread collecting an procsessing data from the BMI270
*	And finally the SPI receive thread, reading the SPI slave
*	For the ISR it handles sending data to the GBP and updating the CS
*	Code for the BMI270 built upon: https://github.com/zephyrproject-rtos/zephyr/tree/main/samples/sensor/bmi270
*	Code for the nrfx timer built upon: https://github.com/nrfconnect/sdk-hal_nordic/tree/9784731461018d3e983604698fbbed6af2bea801/nrfx/samples/src/nrfx_timer/timer/
*	Code for SPI built upon: https://github.com/too1/ncs-spi-master-slave-example
*/


#include <zephyr/kernel.h>
#include <zephyr/device.h>
#include <zephyr/drivers/sensor.h>
#include <zephyr/drivers/gpio.h>
#include <stdio.h>
#include <math.h>
#include <stdbool.h>
#include <nrfx_timer.h>
#include "../include/service.h"
#include "../include/spi.h"
#include "../include/positionCalc.h"
#include <zephyr/drivers/spi.h>

#include <zephyr/types.h>
#include <zephyr/bluetooth/bluetooth.h>
#include <zephyr/bluetooth/uuid.h>
#include <zephyr/bluetooth/gatt.h>
#include <zephyr/bluetooth/hci.h>
#include <bluetooth/gatt_dm.h>
#include <bluetooth/scan.h>

#include <stdlib.h>

#include <zephyr/logging/log.h>

#include <zephyr/drivers/spi.h>


//Bluetooth device
#define DEVICE_NAME CONFIG_BT_DEVICE_NAME
#define DEVICE_NAME_LEN (sizeof(DEVICE_NAME) - 1)

//Log module
#define LOG_MODULE_NAME gameboy_cartridge
LOG_MODULE_REGISTER(LOG_MODULE_NAME, LOG_LEVEL_INF);


//Timing MACROS

/** @brief Symbol specifying sleep time for bluetooth in main and CS (Chip Select)*/
#define MAIN_INTERVAL 50

/** @brief Symbol specifying period of CS (Chip Select) */
#define PERIOD_CS 17

/** @brief Symbol specifying timer instance to be used. */
#define TIMER_INST_IDX 0

/** @brief Symbol specifying time in milliseconds to wait for handler execution. */
#define TIME_TO_WAIT_MS 1UL

/** @brief Symbol for setting stack size for threads. 1024 chosen as pow(2,10) is a safe size.  */
#define STANDARD_STACK_SIZE 1024

/** @brief Symbol for setting stack priority. By using the same priority and yield all threads are able to run.*/
#define STANDARD_PRIORITY 0

/** @brief Set Pin 1.07 as CS driver */
#define CS_GPIO DT_ALIAS(led0)

/** @brief Connect Devicetree information and alias */
static const struct gpio_dt_spec CS = GPIO_DT_SPEC_GET(CS_GPIO, gpios);


//SPI Variables

/** @brief Define S_OUT from GBP*/
#define MY_SPI_SLAVE  DT_NODELABEL(my_spi_slave)

/** @brief Define SPI slave tx buffer */
static uint8_t slave_tx_buffer[2]={0x00,0x00};

/** @brief Define SPI slave receive buffer.
 *  Global variable due to write in interupt and access in spi_trancieve function to achieve
 *  correct timing with communicating with the gameboy*/
static uint8_t slave_rx_buffer[2]={0x00,0x00};

//Timer variables

/** @brief Counter for timing on spi master send*/
volatile uint32_t timerCounter;

/** @brief Value that shows current position of BMI270.*/
volatile uint8_t directionValue;

/** @brief Value to adjust send rate on the SPI to the Gameboy.*/
volatile unsigned long msCounter = 0;

//Bluetooth variables

/** @brief Value sent to recipient through bluetooth.*/
static uint16_t user_value = 0;

/** @brief Value recieved through bluetooth.*/
volatile uint16_t recived_value = 0;

/** @brief Bool to enable sending through bluetooth.*/
bool sendData = false;

/** @brief Bool to enable CS.*/
bool csStatus = false;

/** @brief Counter for enabling CS.*/
uint32_t counter = 0;


static struct bt_conn *current_conn;
static struct bt_conn *default_conn;
static struct bt_gb_client gb_client;
typedef enum {
        peripheral,
        central,
} bt_mode_toggle_type;

bt_mode_toggle_type bt_mode_toggle;

 


K_THREAD_STACK_DEFINE(obtainVal_stack, STANDARD_STACK_SIZE);

struct k_thread obtainVal_id;
//advertising parameters
static const struct bt_data ad[] = {
        BT_DATA_BYTES(BT_DATA_FLAGS, (BT_LE_AD_GENERAL | BT_LE_AD_NO_BREDR)),
        BT_DATA(BT_DATA_NAME_COMPLETE, DEVICE_NAME, DEVICE_NAME_LEN),
};

static const struct bt_data sd[] = {
        BT_DATA_BYTES(BT_DATA_UUID128_ALL, BT_UUID_SERVICE_VAL), 
};

bt_mode_toggle_type toggle_mode_type(bt_mode_toggle_type currentType) {
    return (currentType == peripheral) ? central : peripheral;
}

int start_peripheral(void);
int start_central(void);

//callback function for discovery complete
static void discovery_complete(struct bt_gatt_dm *dm, void *context)
{
        struct bt_gb_client *gb = context;
        LOG_INF("Service discovery complete");

        bt_gatt_dm_data_print(dm);
        bt_gb_handles_assign(dm, gb);
        bt_gb_subscribe_receive(gb);
        
        bt_gatt_dm_data_release(dm);
}
//callback function for discovery
static void discovery_service_not_found(struct bt_conn *conn, void *context)
{
        LOG_INF("Service not found");
}
//callback function for discovery
static void discovery_error(struct bt_conn *conn, int err, void *context)
{
        LOG_WRN("Error while discovering GATT database: (%d)", err);
}
//setting callbacks for discovery phase
struct bt_gatt_dm_cb discovery_cb = {
        .completed = discovery_complete,
        .service_not_found = discovery_service_not_found,
        .error_found = discovery_error,
};
//starting discovery process
static void gatt_discover(struct bt_conn *conn)
{
        int err;

        if (conn != default_conn){
                return;
        }

        err = bt_gatt_dm_start(conn, BT_UUID_GB_SERVICE, &discovery_cb, &gb_client);
        if (err) {
                LOG_ERR("Could not start the discovery prodcedure, error (%d)", err);
        }
}
//exchange MTU with connected device
static void exchange_func(struct bt_conn *conn, uint8_t err, struct bt_gatt_exchange_params *params)
{
	if (!err) {
		LOG_INF("MTU exchange done");
	} else {
		LOG_WRN("MTU exchange failed (err %" PRIu8 ")", err);
	}
}
//connection callback
static void connected(struct bt_conn *conn, uint8_t err)
{       
        char addr[BT_ADDR_LE_STR_LEN];

        if (err) {
                LOG_ERR("Connection failed (err %u)", err);
                return;
                if (bt_mode_toggle == central){
                        err = bt_scan_start(BT_SCAN_TYPE_SCAN_ACTIVE);
                        if (err) {
                                LOG_ERR("Scanning failed to start (err %d)", err);
                        }
                }
                return;
        }
        bt_addr_le_to_str(bt_conn_get_dst(conn), addr, sizeof(addr));
        LOG_INF("Connected %s", addr);

        static struct bt_gatt_exchange_params exchange_params;

        exchange_params.func = exchange_func;
        err = bt_gatt_exchange_mtu(conn, &exchange_params);
        if (err) {
              LOG_WRN("MTU exchange failed (err %d)", err);  
        }

        err = bt_scan_stop();
        if ((!err) && (err != -EALREADY)) {
                LOG_ERR("Stop LE scan failed (err %d)", err);
        }

        current_conn = bt_conn_ref(conn);

        gatt_discover(conn);
}
//disconnect callback
static void disconnected(struct bt_conn *conn, uint8_t reason)
{
        char addr[BT_ADDR_LE_STR_LEN];
        int err;

        bt_addr_le_to_str(bt_conn_get_dst(conn), addr, sizeof(addr));

        LOG_INF("Disconnected: %s (reason %u)", addr, reason);

        if(default_conn != conn){
                return;
        }
	//if the device is in central mode it should start scanning process if disconnected
        if (bt_mode_toggle == central){ 
                bt_conn_unref(default_conn);
                default_conn = NULL;
                err = bt_scan_start(BT_SCAN_TYPE_SCAN_ACTIVE);
                if (err) {
                        LOG_ERR("Scanning failed to start (err %d)", err);
                }
        } else { 
                bt_conn_unref(current_conn);
                current_conn = NULL;
        }      
}
//callback for filter match
static void scan_filter_match(struct bt_scan_device_info *device_info, struct bt_scan_filter_match *filter_match, bool connectable)
{
        char addr[BT_ADDR_LE_STR_LEN];
        bt_addr_le_to_str(device_info->recv_info->addr, addr, sizeof(addr));

        LOG_INF("Filters matched. Address: %s connectable: %d", addr, connectable);
}
//scanning callback
static void scan_connecting_error(struct bt_scan_device_info *device_info)
{
        LOG_WRN("Connecting failed");
}
//scanning callback
static void scan_connecting(struct bt_scan_device_info *device_info, struct bt_conn *conn)
{
        LOG_INF("scan_connecting");
        default_conn = bt_conn_ref(conn);
}
//scanning callback
static void filter_no_match(struct bt_scan_device_info *device_info,
				bool connectable)
{
        char addr[BT_ADDR_LE_STR_LEN];
        bt_addr_le_to_str(device_info->recv_info->addr, addr, sizeof(addr));
        LOG_INF("Filters not matched. Address: %s", addr);
}
//callback for data send for central
static void ble_data_sent(struct bt_gb_client *gb, uint8_t err, const uint16_t *const data, uint16_t len)
{
        ARG_UNUSED(gb);
        ARG_UNUSED(len);
        LOG_INF("ble_data_sent");
        if (err) {
                LOG_WRN("ATT error code:0x%02X", err);
        } else {
                LOG_INF("Data sent: %u", *data);
        }
}
//callback for data received for central
static uint8_t ble_data_received(struct bt_gb_client *gb, const uint16_t *data, uint16_t len)
{
        ARG_UNUSED(gb);
        ARG_UNUSED(len);

        LOG_INF("ble_data_received");
        LOG_INF("Data received %u", *data);
        return BT_GATT_ITER_CONTINUE;
}
//callback for data received for peripheral
static void bt_receive_cb(struct bt_conn *conn, const uint16_t *const data, uint16_t len)
{
    char addr[BT_ADDR_LE_STR_LEN] =  {0};

    bt_addr_le_to_str(bt_conn_get_dst(conn), addr, ARRAY_SIZE(addr));
    recived_value = *data;

    LOG_INF("Received data: %u, from %s", recived_value, addr);
};
//bluetooth initialization and callback init for central
static int bt_client_init(void)
{
        int err;
        struct bt_gb_client_init_param init = {
                .cb = {
                        .received = ble_data_received,
                        .sent = ble_data_sent,
                }
        };

        err = bt_gb_client_init(&gb_client, &init);

        if (err) {
                LOG_ERR("Gameboy client initialization failed (err %d)", err);
                return err;
        }
        LOG_INF("Gameboy client initialized");
        return err;
}

BT_SCAN_CB_INIT(scan_cb, scan_filter_match, filter_no_match, scan_connecting_error, scan_connecting);

BT_CONN_CB_DEFINE(conn_callbacks) = {
	.connected    = connected,
	.disconnected = disconnected,
};
//scanning module initialization
static int scan_init(void)
{
        int err;
        struct bt_scan_init_param scan_init = {
                .connect_if_match = 1,
        };

        bt_scan_init(&scan_init);
        bt_scan_cb_register(&scan_cb);

        err = bt_scan_filter_add(BT_SCAN_FILTER_TYPE_UUID, BT_UUID_GB_SERVICE);
	if (err) {
		LOG_ERR("Scanning filters cannot be set (err %d)", err);
		return err;
	}

        err = bt_scan_filter_enable(BT_SCAN_UUID_FILTER, false);
        if (err) {
                LOG_ERR("Filters cannot be turned on (err %d)", err);
                return err;
        }

        LOG_INF("Scan module initialized");
        return err;
}
//register callback for peripheral
static struct bt_cb gb_cb = {
    .received = bt_receive_cb,
};

//function for switching betwwen bluetooth modes
void mode_toggle()
{
        switch (bt_mode_toggle)
        {
        case central:
                start_central();
                break;

        case peripheral:
                start_peripheral();
                break;

        default:
                break;
        }
}

void mode_change_recived(uint8_t mode)
{
        if(mode == 0xFD){
                LOG_INF("Mode change received");
                bt_mode_toggle = toggle_mode_type(bt_mode_toggle);
                mode_toggle();
                slave_rx_buffer[1]--;

        }

        if(sendData == true){
                sendData = false;
                LOG_INF("Sending");
                if(bt_mode_toggle == peripheral){
                        int err = bt_gb_send(NULL, &user_value, sizeof(user_value));
                        if (err) {
                                LOG_ERR("Failed to send (%d)", err);
                        }
                } else if (bt_mode_toggle == central){
                        int err = bt_gb_write(&gb_client, &user_value, sizeof(user_value));
                        if (err) {
                                LOG_ERR("Failed to send (%d)", err);
                        }
                }
        }
        }

//initializing bluetooth central 
int start_central(void)
{
        int err;
        err = scan_init();
        if (err){
                LOG_ERR("scan_init failed (err %d)", err);
                return err;
        }

        err = bt_client_init();
        if (err) {
                LOG_ERR("bt_gb_client_init failed (err %d)", err);
                return err;
        }
        err = bt_scan_start(BT_SCAN_TYPE_SCAN_ACTIVE);
        if (err) {
                LOG_ERR("Scanning failed to start (err %d)", err);
                return err;
        }
        LOG_INF("Scanning started");
        return 0;
}

//initialization of bluetooth peripheral
int start_peripheral(void)
{
        int err;
        err = bt_le_adv_start(BT_LE_ADV_CONN, ad, ARRAY_SIZE(ad), sd, ARRAY_SIZE(sd));
        if (err) {
                LOG_ERR("Advertising failed to start (%d)", err);
                return err;
        }

        LOG_INF("Advertising has started");
        return 0;
}

void GameboyReciveAndSend(int emptyData, volatile uint8_t tiltData)
{
        timerCounter++; 
        if(timerCounter > 8)
        {
                msCounter++;
                if(msCounter >= tiltValue)
                {
                        spi_write_test_msg(tiltData);
                        msCounter = 0;
                }

                else
                {
                        spi_write_test_msg(emptyData);
                }
                timerCounter = 0;
                slave_rx_buffer[1]--;
        }
}

static void timer_handler(nrf_timer_event_t event_type, void * p_context)
{
        
    if(event_type == NRF_TIMER_EVENT_COMPARE0)
    {
        if( slave_rx_buffer[1] == 0xFE)
        {
               timerCounter++;
               if(timerCounter <= 1)
               {
                        spi_write_test_msg(directionValue);  
                        timerCounter = 0;
                        slave_rx_buffer[1]--;
                        slave_rx_buffer[0]--;
               }
        }

        if(slave_rx_buffer[1] == 0x69)
        {
                if(recived_value < user_value && user_value >= 10)
                {
                        GameboyReciveAndSend(0x00,0x77);
                }
                
                else if (recived_value > user_value && user_value >= 10)
                {
                        GameboyReciveAndSend(0x00,0x13);
                }
                else
                {
                        GameboyReciveAndSend(0x00,directionValue);
                }
                
        }

        if(slave_rx_buffer[1] != 0x68 && slave_rx_buffer[1] != 0x69 && slave_rx_buffer[1] != 0xFE && 
           slave_rx_buffer[1] != 0xFD && slave_rx_buffer[1] != 0xFC && slave_rx_buffer[1] != 0x00 &&
           slave_rx_buffer[1] != 0x26 && slave_rx_buffer[1] != 0x49 && slave_rx_buffer[1] != 0x34 && 
           slave_rx_buffer[1] != 0xD2 && slave_rx_buffer[1] != 0xA4 && slave_rx_buffer[1] != 0x4D && 
           slave_rx_buffer[1] != 0x93 && slave_rx_buffer[1] != 0x9A && slave_rx_buffer[1] != 0xAA)
        {
                sendData = true;
                user_value = slave_rx_buffer[1];
                GameboyReciveAndSend(0x00,directionValue);
                slave_rx_buffer[1]=0x00;
        }
        

        if(counter >= PERIOD_CS)
        {
                counter = 0;
                ret =gpio_pin_set_dt(&CS, 0);
                csStatus = !csStatus;
                if (ret < 0) {
                return 0;
                }
        }
        else
        {
                ret = gpio_pin_set_dt(&CS,1);
                csStatus = !csStatus;
                if (ret < 0) {
                        return 0;
                }	
                counter++;
        }
        
    }
}



//NRFX enable from the source in introduction
void nrfx_enable(void)
{
	nrfx_err_t status;
    (void)status;

	nrfx_timer_t timer_inst = NRFX_TIMER_INSTANCE(TIMER_INST_IDX);
    uint32_t base_frequency = NRF_TIMER_BASE_FREQUENCY_GET(timer_inst.p_reg);
    nrfx_timer_config_t config = NRFX_TIMER_DEFAULT_CONFIG(base_frequency);
    config.bit_width = NRF_TIMER_BIT_WIDTH_32;
    config.p_context = "Some context";

	status = nrfx_timer_init(&timer_inst, &config, timer_handler);
    NRFX_ASSERT(status == NRFX_SUCCESS);

	#if defined(__ZEPHYR__)
    IRQ_DIRECT_CONNECT(NRFX_IRQ_NUMBER_GET(NRF_TIMER_INST_GET(TIMER_INST_IDX)), IRQ_PRIO_LOWEST,
                       NRFX_TIMER_INST_HANDLER_GET(TIMER_INST_IDX), 0);
	#endif

	 nrfx_timer_clear(&timer_inst);

    /* Creating variable desired_ticks to store the output of nrfx_timer_ms_to_ticks function */
    uint32_t desired_ticks = nrfx_timer_ms_to_ticks(&timer_inst, TIME_TO_WAIT_MS);
    //printk("Time to wait: %lu ms", TIME_TO_WAIT_MS);

    /*
     * Setting the timer channel NRF_TIMER_CC_CHANNEL0 in the extended compare mode to clear the timer and
     * trigger an interrupt if internal counter register is equal to desired_ticks.
     */
    nrfx_timer_extended_compare(&timer_inst, NRF_TIMER_CC_CHANNEL0, desired_ticks,
                                NRF_TIMER_SHORT_COMPARE0_CLEAR_MASK, true);

    nrfx_timer_enable(&timer_inst);
}

// SPI slave functionality

//SPI slave device
const struct device *spi_slave_dev;

//K poll signal for SPI slave
static struct k_poll_signal spi_slave_done_sig = K_POLL_SIGNAL_INITIALIZER(spi_slave_done_sig);

//SPI slave configuration
static const struct spi_config spi_slave_cfg = {
	.operation = SPI_WORD_SET(8) | SPI_TRANSFER_MSB |
				 SPI_MODE_CPOL | SPI_MODE_CPHA | SPI_OP_MODE_SLAVE,
	.frequency = 8192,
	.slave = 0,
};

//SPI slave initialization
void spi_slave_init(void)
{
	spi_slave_dev = DEVICE_DT_GET(MY_SPI_SLAVE);
	if(!device_is_ready(spi_slave_dev)) {
		LOG_INF("SPI slave device not ready!\n");
	}
}
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
int main(void)
{
        startObtainVal();
        LOG_INF("Starting GameBoy Cartridge");
        int err = 0;
        int blink_status = 0;
        int ret;
	//initialize modules
        err = bt_enable(NULL);
        if (err) {
                LOG_ERR("Failed to enable bluetooth (%d)", err);
                return err;
        }
        err = bt_gb_init(&gb_cb);
        if (err) {
                LOG_ERR("Failed to initialize GameBoy service (%d)", err);
        }
        if (!device_is_ready(CS.port)) {
		return 0;
	}

	ret = gpio_pin_configure_dt(&CS, GPIO_OUTPUT_ACTIVE);
	if (ret < 0) {
		return 0;
	}

        change_gpio_voltage(UICR_VREGHVOUT_VREGHVOUT_3V0);

        start_peripheral();

        for (;;) {
                k_sleep(K_MSEC(MAIN_INTERVAL));
                mode_change_recived(slave_rx_buffer[1]);
                if (nanFlag == true){
                nanFlag = false;
                LOG_INF("Nan detected");
                k_thread_abort(&obtainVal_id);
                k_sleep(K_MSEC(MAIN_INTERVAL));
                startObtainVal();
                }
                k_yield();
        }   	
}

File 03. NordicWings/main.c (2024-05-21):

#include <stdio.h>
#include <gb/gb.h>
#include <gb/drawing.h>
#include <gb/metasprites.h>
#include <string.h>
#include <stdint.h>

#include "Splashscreen.h"
#include "Rings.h"
#include "Amogus.h"
#include "Cockpit.h"
#include "Numbers.h"

uint8_t i;  // Used as a counter in the fade functions
uint8_t oldShiftx;  // Used to dynamically update rings. Needs to be initialized here to not constantly re-initialize in the function.
uint8_t oldShifty;
uint8_t score = 1;
uint8_t p2score;
uint8_t playMode;

// OK BROTHER HERE IS WHAT YOU DO (note to self)
// cd Documents\VSCstuff\Projects\GB\Examples\"03. NordicWings"
// .\compile.bat

/* WELCOME TO THE NORDICWINGS BACKROOMS



Info:
LUTs with pre-calculated values were used instead of doing the calculations in the code as trigonometry is not practically possible in standard C.
They also had the added benefit of being efficient and low cost compared to continuous calculation.

The BGP_REG register is used to alter the indexes of the Gameboy color palette. In this code, it is used to fade in and out images on screen.

Metasprites are great for smaller sprites, but for larger as the rings, this is a silly undertaking.
The gameboy can at max render 40 individual sprites on the sprite layer at a time, so any rings larger than ring 7 would be over that amount and would not load.
Ring 8 has cut down sides to account for this and allow for a larger defined ring.
move_metasprite_ex schedules the metasprite to be moved in the next vertical blank. The sprite does not move immediately.

While global variables are bad code practice, they are a lot more efficient in a GBDK-setting as they are not stored on the stack like local ones and don't have the
absolute addresses calculated by the compiler every time they are used. Instead, they are statically allocated in RAM which in most cases makes the code more efficient.
Source: https://gbdk.sourceforge.net/doc/html/c0204.html

Linear Congruential Generator (LCG) is used as a pseudo-randomizer for ring generation. This algorithm is relatively simple, fast and cost efficient to run on the
gameboy hardware.


Author: Jesper Reksten
Co-authors: Fredrik Kihl, Halvor Arnesen
Version: 1.2
Last updated: 15.05.24



*/

void ClearScreen()  // To be called to completely clear a screen. Not efficient, call only when nessecary
{
    color(WHITE, WHITE, SOLID); // Sets fore- and background color
    box(0, 0, GRAPHICS_WIDTH, GRAPHICS_HEIGHT, M_FILL); // Fills box from 0,0 to 159,143 with selected color
    color(BLACK, WHITE, SOLID);
}

void safedelay(uint8_t numloops)    // Custom delay function using vertical blank instead of delay() to not max out cpu. "numloops" = 60 each second.
{                                   // Original author unknown, seen variations of this used in many different projects.
    uint8_t n;
    for(n = 0; n < numloops; n++)
    {
        vsync();
    }
}





void fadeo(uint8_t frames)    // Fade out current image
{
    for (i = 0; i < 4; i++)
    {
        switch (i)
        {
            case 0:
                BGP_REG = 0xE4;
                break;
            case 1:
                BGP_REG = 0x90;
                break;
            case 2:
                BGP_REG = 0x40;
                break;
            case 3:
                BGP_REG = 0x00;
                break;
        }
        safedelay(frames);  // 60 frames = 1 second
    }
}

void fadei(uint8_t frames)    // Fade in current image
{
    for (i = 0; i < 4; i++)
    {
        switch (i)
        {
            case 0:
                BGP_REG = 0x00;
                break;
            case 1:
                BGP_REG = 0x40;
                break;
            case 2:
                BGP_REG = 0x90;
                break;
            case 3:
                BGP_REG = 0xE4;
                break;
        }
        safedelay(frames);
    }
}





#pragma region Animation Stuff

uint8_t animationIndex = 0;
uint8_t frameCount = 0;    // Both used for a delay-less animation
uint8_t framesPerStep = 40;  // Number of frames before changing frame (20 = 3 times per second)

#pragma endregion

#pragma region Metasprites

const metasprite_t ring1_metasprite[] = {
    {.dy=-8, .dx=-8, .dtile=1, .props = 0x80},   // This first line dictates the pivot of the rest of the sprite
    {.dy=0, .dx=8, .dtile=2, .props = 0x80},     // .dx abd .dy are relative positions to the pivot
    {.dy=8, .dx=-8, .dtile=3, .props = 0x80},    // .props = 0x80 makes the sprite be rendered below the window
    {.dy=0, .dx=8, .dtile=4, .props = 0x80},
    METASPR_TERM
};
const metasprite_t ring2_metasprite[] = {
    {.dy=-8, .dx=-8, .dtile=5, .props = 0x80},
    {.dy=0, .dx=8, .dtile=6, .props = 0x80},
    {.dy=8, .dx=-8, .dtile=7, .props = 0x80},
    {.dy=0, .dx=8, .dtile=8, .props = 0x80},
    METASPR_TERM
};
const metasprite_t ring3_metasprite[] = {
    {.dy=-8, .dx=-8, .dtile=9, .props = 0x80},
    {.dy=0, .dx=8, .dtile=10, .props = 0x80},
    {.dy=8, .dx=-8, .dtile=11, .props = 0x80},
    {.dy=0, .dx=8, .dtile=12, .props = 0x80},
    METASPR_TERM
};
const metasprite_t ring4_metasprite[] = {
    {.dy=-16, .dx=-16, .dtile=1, .props = 0x80},
    {.dy=0, .dx=8, .dtile=13, .props = 0x80},
    {.dy=0, .dx=8, .dtile=13, .props = 0x80},
    {.dy=0, .dx=8, .dtile=2, .props = 0x80},

    {.dy=8, .dx=-24, .dtile=14, .props = 0x80},
    {.dy=0, .dx=24, .dtile=15, .props = 0x80},

    {.dy=8, .dx=-24, .dtile=14, .props = 0x80},
    {.dy=0, .dx=24, .dtile=15, .props = 0x80},

    {.dy=8, .dx=-24, .dtile=3, .props = 0x80},
    {.dy=0, .dx=8, .dtile=16, .props = 0x80},
    {.dy=0, .dx=8, .dtile=16, .props = 0x80},
    {.dy=0, .dx=8, .dtile=4, .props = 0x80},
    METASPR_TERM
};
const metasprite_t ring5_metasprite[] = {
    {.dy=-16, .dx=-16, .dtile=9, .props = 0x80},
    {.dy=0, .dx=8, .dtile=16, .props = 0x80},
    {.dy=0, .dx=8, .dtile=16, .props = 0x80},
    {.dy=0, .dx=8, .dtile=10, .props = 0x80},

    {.dy=8, .dx=-24, .dtile=15, .props = 0x80},
    {.dy=0, .dx=24, .dtile=14, .props = 0x80},

    {.dy=8, .dx=-24, .dtile=15, .props = 0x80},
    {.dy=0, .dx=24, .dtile=14, .props = 0x80},

    {.dy=8, .dx=-24, .dtile=11, .props = 0x80},
    {.dy=0, .dx=8, .dtile=13, .props = 0x80},
    {.dy=0, .dx=8, .dtile=13, .props = 0x80},
    {.dy=0, .dx=8, .dtile=12, .props = 0x80},
    METASPR_TERM
};
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

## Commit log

2024-04-10 Saved in case
2024-04-11 Faulty, but functional BMI270 to PWM
2024-05-07 PCB layout
2024-05-19 PCB documents
    [GameBoy_Link_bom_nems.xls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]
2024-05-21 Added STL for PCB case
    [Gamelink.stl]
2024-05-21 Added link cable plug STL
    [Link Cable GBP.stl]
